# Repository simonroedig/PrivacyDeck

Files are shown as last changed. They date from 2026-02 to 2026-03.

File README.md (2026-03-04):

# PrivacyDeck

**Tangible Privacy Control. Zero Effort. Always Aware.**

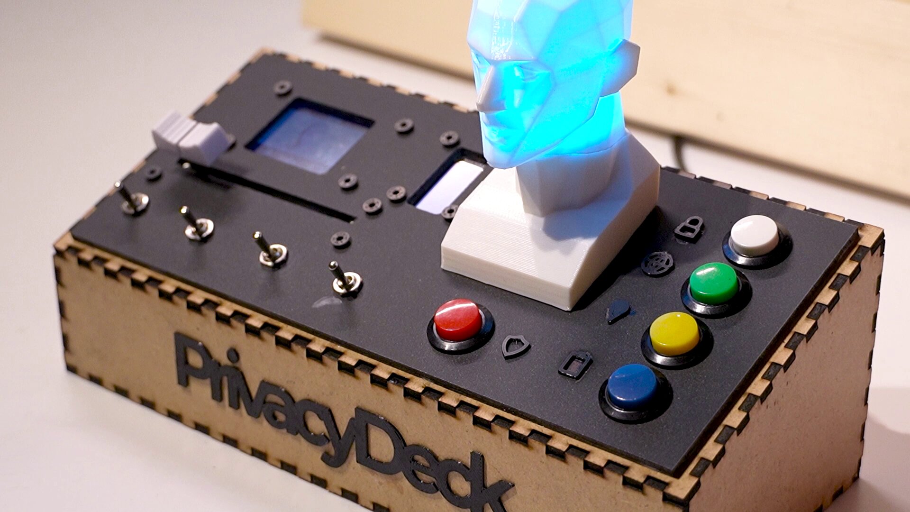
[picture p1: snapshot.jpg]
PrivacyDeck


*Built for the course **Practical Privacy and Security (PPS)** at LMU Munich*

---

## Video Demonstration:
<a href="https://www.youtube.com/watch?v=T16Eui8qbHk" target="_blank">
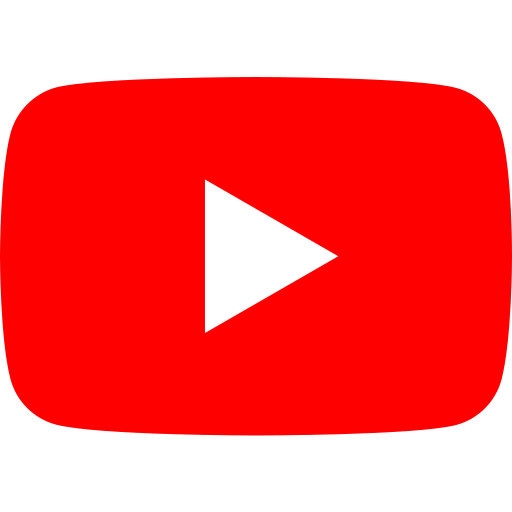
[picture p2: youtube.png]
Watch the video demonstration
    
</a>

## The Problem

Although privacy tools exist, they are buried deep inside complex, fragmented OS settings. There is **no unified control dashboard** and **no immediate feedback**.  
Most users therefore never enable protective features, preferring convenience over security — exposing themselves to risks such as unauthorized camera/microphone access, background data leaks, and embarrassing “always-on” moments.

## Our Vision

**PrivacyDeck envisions a world where privacy protection requires no effort.**  
Awareness alone is enough.  
No one ever has to worry about an embarrassing moment again.

---

## What is PrivacyDeck?

**PrivacyDeck** is a compact, USB-connected **physical control panel** that gives you **tangible, intuitive control** over all core privacy & security functions of your computer — at the press of a button or flip of a toggle.

- Personalized **avatar** on a small display that reflects your current privacy state via LEDs 
- Physical buttons, toggles & slider for instant action  
- Real-time visual & haptic feedback  
- Works with Linux (fully tested on Zorin OS), partially with Windows 11, and partially with macOS

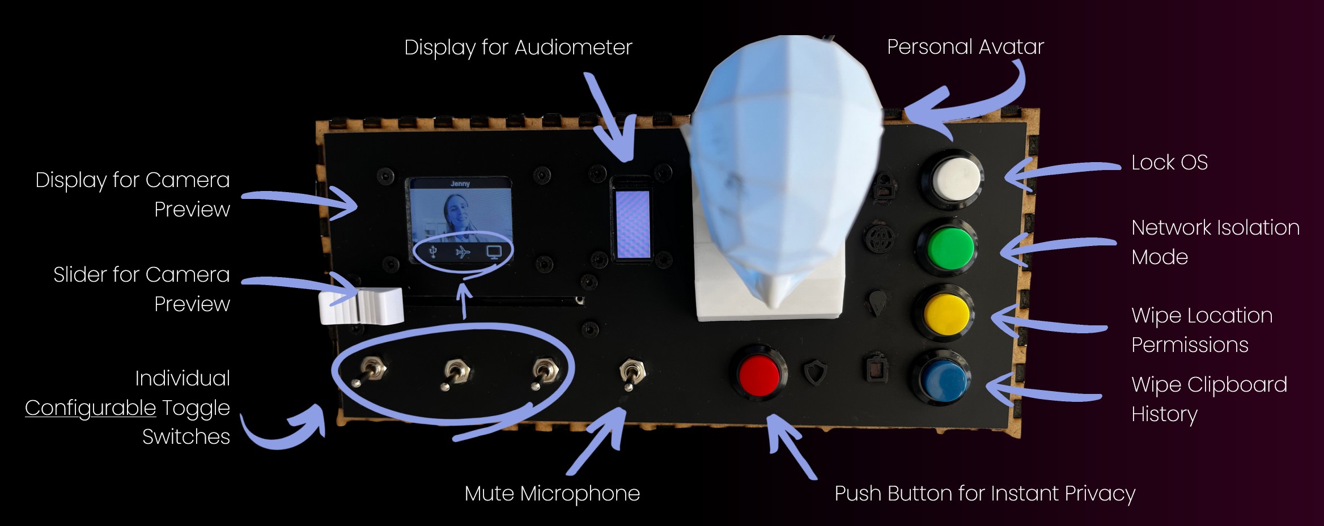
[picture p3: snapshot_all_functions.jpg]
All Functions Explained


---

## Repository Structure

```bash
PrivacyDeck/
├── verticalPrototype/                    # First working vertical prototype
├── 3d/                                   # All 3D-printable assets (avatar, etc.)
├── lasercut/                             # Laser-cut files for the case
│
├── privacyDeck/
│   ├── os/                               # Final OS-side daemon (Python)
│   │   └── final_main_os.py              # Main daemon – recommended on Linux
│   └── piPico/                           # Code for the Raspberry Pi Pico
│       └── final_main_pico.py            # Load as main.py on the Pico
│
└── guisoftware/                          # Graphical UI prototype (digital avatar + config)
```

---

## Hardware

- **Microcontroller**: Raspberry Pi Pico (RP2040)
- **Display**: Small TFT showing webcam and audio meter
- **Controls**: Buttons, toggles, slider, neopixel led
- **Connection**: Single USB cable (power + serial communication)

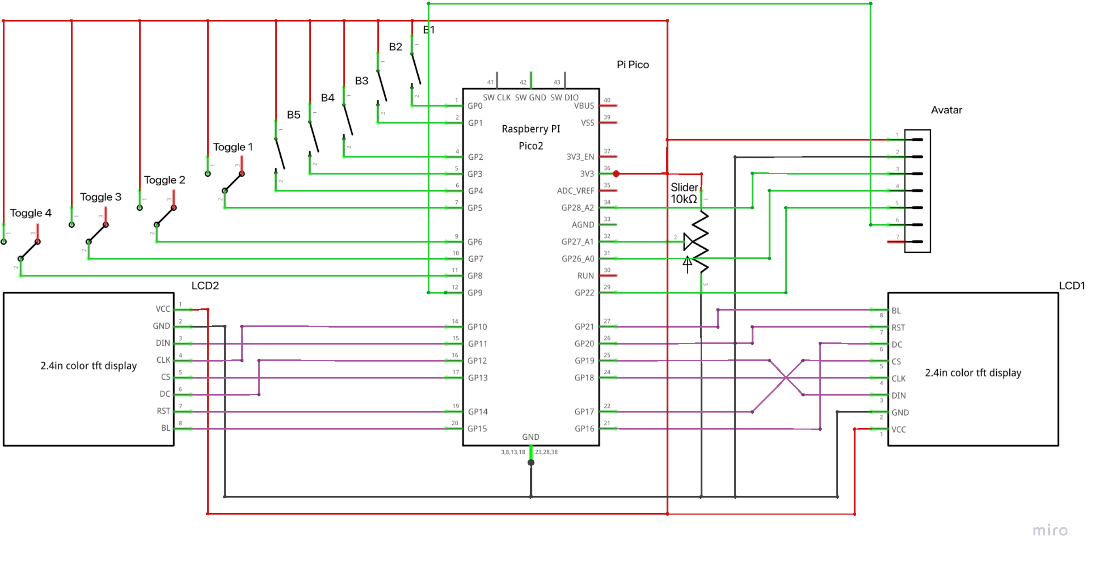
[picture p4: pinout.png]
Raspberry Pi Pico Pinout


**Early vertical prototype:**

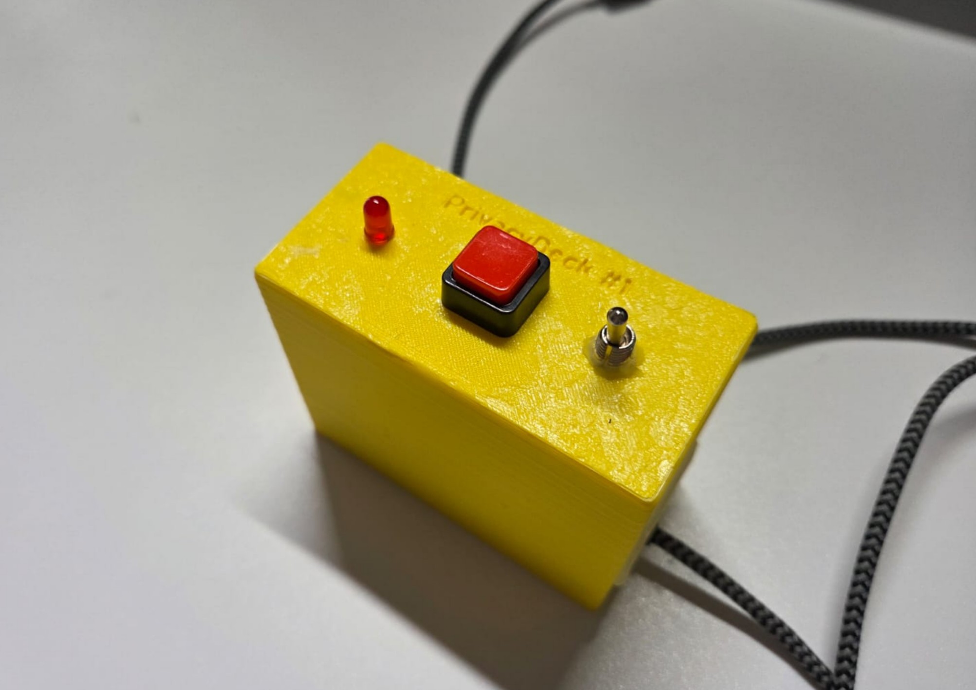
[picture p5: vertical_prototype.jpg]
Vertical Prototype


---

## Software

### 1. Raspberry Pi Pico (hardware side)
1. Copy `privacyDeck/piPico/final_main_pico.py` to the Pico as `main.py` and also include all other files
2. The Pico will automatically run and expose a serial port

### 2. Host OS Daemon (Linux / Windows)
1. `cd privacyDeck/os`
2. Make sure the serial port of the Pico is free
3. Run:
   ```bash
   python3 final_main_os.py
   ```
   (or `python final_main_os.py` on Windows)

**Tested & fully working on:**
- **Linux** – Zorin OS (primary development platform)
**Windows 11** – partially integrated (some triggers work with GUI solutions, full testing pending)
**macOS** – partially integrated (some triggers work, full testing pending)

### 3. GUI Software Prototype (optional but awesome)
Located in `guisoftware/`. Shows a beautiful digital avatar, live privacy status, and full configuration of every button/toggle.
Integration to the Python Daemon pending.

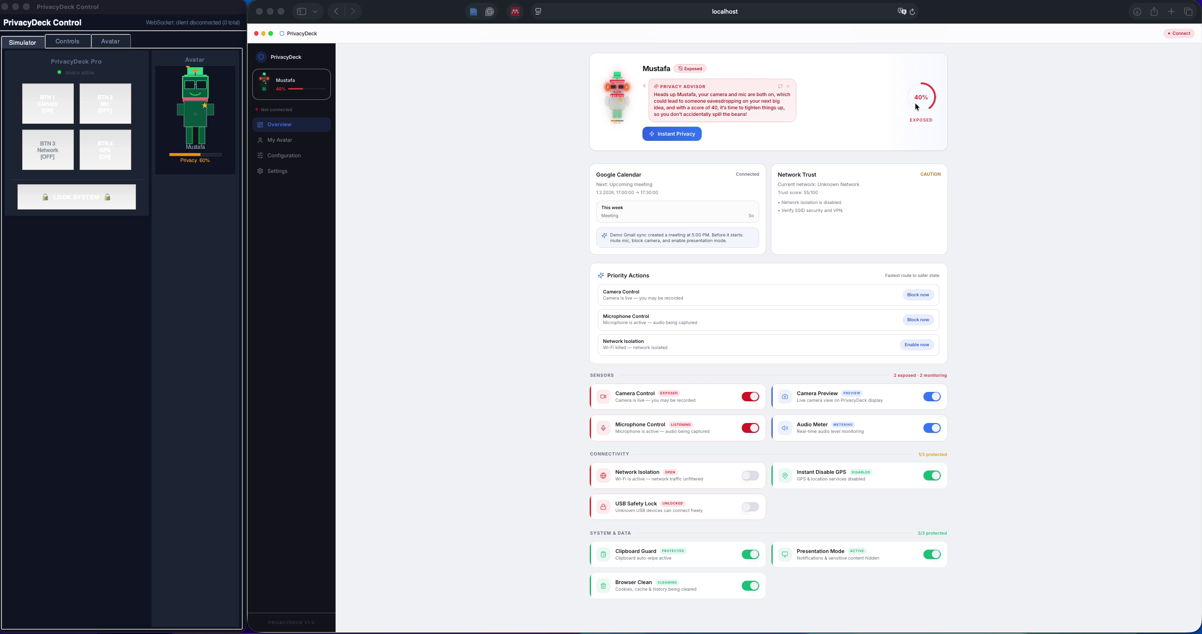
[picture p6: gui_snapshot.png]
GUI Prototype


---

## How to Get Started (Quick Guide)

1. Laser-cut the enclosure (`lasercut/`)
2. 3D-print the avatar holder and details (`3d/`)
3. Flash the Pico with `final_main_pico.py`
4. Connect everything via USB
5. Run `final_main_os.py` on your computer
6. Enjoy instant, physical privacy control!

---

## Team

- **Franziska Oberländer**
- **Mustafa Durani**
- **Tristan Häuser**
- **Simon Rödig** 

---

**Course**  
Practical Privacy and Security (PPS)  
Ludwig-Maximilians-Universität München (LMU)  
Winter Semester 2025/26

---

**Made with ❤️ for privacy that finally feels effortless.**

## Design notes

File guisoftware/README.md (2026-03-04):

# PrivacyDeck

A physical desktop privacy control panel — hardware-level privacy controls for macOS, paired with a companion dashboard app.

---

## What is PrivacyDeck?

PrivacyDeck is a two-part system:

1. **Physical device** — a microcontroller-based controller (current prototype appears to be ESP32-class hardware) that sits on your desk with buttons mapped to privacy features
2. **Companion dashboard** — a React/Vite app running locally on your Mac, showing real-time privacy status, a configurable avatar, and controls for all features

The two communicate via:
- **Wi-Fi TCP socket (port 50555)** — the hardware controller sends button events to the Python daemon
- **WebSocket (port 50556)** — the React dashboard connects to the daemon to read state, toggle features, and receive live updates

---

## Architecture

```
React Dashboard (Vite + TypeScript, port 8080)
  |  WebSocket ws://localhost:50556
Python Daemon (daemon/main.py)
  |  TCP :50555
Hardware Controller (buttons, LEDs)
```

---

## Current Hardware Status

- ✅ Physical button hardware has replaced the simulator.
- ℹ️ Based on the current prototype board shape/module, it appears to be an **ESP32 dev board** rather than a Raspberry Pi Pico; confirm by reading the silkscreen/chip label on the PCB (e.g. `ESP32`, `WROOM`, or RP2040-related marking).
- ⚠️ Main integration blockers encountered during bring-up:
  - Campus **eduroam restrictions** prevented reliable device-to-daemon networking.
  - **Python environment setup** issues delayed daemon-side testing and validation.

---

## Privacy Features

| Feature | Type | Active = |
|---|---|---|
| Camera Control | Exposure | Camera live (risk) |
| Microphone Control | Exposure | Mic active (risk) |
| Camera Preview | Monitor | Live preview on device display |
| Audio Meter | Monitor | Real-time level metering |
| Network Isolation | Protection | Wi-Fi killed (safe) |
| Instant Disable GPS | Protection | Location services off (safe) |
| USB Safety Lock | Protection | Unauthorised USB blocked (safe) |
| Clipboard Guard | Protection | Clipboard auto-wipe on (safe) |
| Presentation Mode | Protection | Notifications hidden (safe) |
| Browser Clean | Protection | Cache & cookie clearing active (safe) |

**Privacy Score (0–100%):**
- 40 pts — exposure safety (camera + mic both off = full 40)
- 60 pts — protection coverage (all guards enabled = full 60)

**Instant Privacy** — one button blocks all sensors and enables all protections simultaneously.

---

## Requirements

### Dashboard
- Node.js >= 18 or Bun

### Daemon
- Python 3.10+
- macOS (primary; Linux/Windows partial support)

---

## Getting Started

### 1. Start the Python daemon

```bash
cd daemon
python3 -m venv ../.venv
source ../.venv/bin/activate
pip install -r requirements.txt
python main.py
```

The daemon opens a Tkinter control window and starts the WebSocket server on `ws://localhost:50556`.

### 2. Start the React dashboard

```bash
npm install        # or: bun install
npm run dev        # http://localhost:8080
```

Open http://localhost:8080. The dashboard auto-connects to the daemon. Use the **Connect Device** button in the top bar if the connection indicator is red.

### 3. Configure and flash the hardware firmware

Edit `firmware/privacydeck_esp32/privacydeck_esp32.ino` before flashing:

- Set `WIFI_SSID` and `WIFI_PASSWORD` to a Wi-Fi network that your Mac and board can both access.
- Set `SERVER_HOST` to your Mac's LAN IP address (the machine running `python main.py`).
- Keep `SERVER_PORT` as `50555` unless you also change the daemon port.

Then flash the board from Arduino IDE / PlatformIO and open Serial Monitor at `115200` baud.

### 4. Verify button presses are registered in the dashboard

When connection is healthy, you should see this flow:

1. Hardware logs handshake success (`HELLO ...` / `HELLO_ACK ...`).
2. Daemon window logs `Pico TCP: connected ...` and then receives button events.
3. On press, firmware sends `EVENT BUTTON_1..4 pressed` (or `LOCK_BUTTON`).
4. Daemon responds `OK`, toggles the mapped feature, and broadcasts a WebSocket update.
5. Dashboard cards/status update immediately via `ack` / `feature_update` messages.

If presses do not appear in UI:

- Verify Mac firewall allows inbound TCP on `50555` and WS on `50556`.
- Ensure both devices are on a network that allows client-to-client traffic (many eduroam setups block this).
- Confirm button mappings in the dashboard Configuration page match expected features.
- Recheck firmware `SERVER_HOST` IP after reconnecting to a different network.

---

## Project Structure

```
privacy-dashboard-pro-main/
  daemon/
    main.py               Entry point, Tkinter GUI, server bootstrap
    ws_server.py          Async WebSocket server
    mic_control.py        Mute/unmute microphone
    webcam.py             Camera privacy level control
    audio_meter.py        Real-time audio level metering
    airplane.py           Wi-Fi kill switch (Network Isolation)
    location.py           GPS / Location Services toggle
    usb_alert_control.py  USB device alert/block
    clipboard_control.py  Clipboard wipe
    blackout.py           Screen blackout overlay
    lock_control.py       Trigger OS lock screen
    requirements.txt
  src/
    components/
      PrivacyAvatar.tsx   Robot SVG avatar with health bar and dead-eyes at 0%
      AppSidebar.tsx      Navigation sidebar with live privacy score bar
      MacOSChrome.tsx     Title bar with connection status indicator
    context/
      PrivacyContext.tsx  Feature state, WebSocket client, optimistic updates
      AvatarContext.tsx   Avatar customisation state
    pages/
      Overview.tsx        Main dashboard (feature cards + privacy score hero)
      Configuration.tsx   Physical button mapping
      AvatarPage.tsx      Full avatar customiser
      SettingsPage.tsx    App preferences
      AboutPage.tsx       About
    hooks/
      useWebSocket.ts     Reconnecting WebSocket with exponential backoff
```

---

## Avatar Health System

The robot avatar reflects your privacy score as a live health bar:

| Score | State | Visuals |
|---|---|---|
| 70–100% | Healthy | Green bar, full opacity body |
| 30–69% | At risk | Amber bar, reduced body opacity |
| 1–29% | Critical | Red bar, pulsing LOW HP badge |
| 0% | Dead | XX eyes, flat-line mouth, dizzy swirl, faded body |

---

## WebSocket Protocol

All messages are JSON over `ws://localhost:50556`.

**Daemon → Dashboard:**

| Type | Payload | When |
|---|---|---|
| `state` | `{ features, buttonMapping }` | On connect |
| `ack` | `{ featureId, active, success }` | After toggle |
| `feature_update` | `{ featureId, active }` | Push update |
| `error` | `{ message, featureId? }` | On failure |

**Dashboard → Daemon:**

| Type | Payload | Action |
|---|---|---|
| `toggle` | `{ featureId }` | Toggle a feature |
| `get_state` | — | Request full state snapshot |
| `set_button_mapping` | `{ mapping: string[] }` | Update button assignments |

---

## Running Tests

```bash
npm test            # single run
npm run test:watch  # watch mode
```

---

## License

MIT

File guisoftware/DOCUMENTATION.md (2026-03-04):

# PrivacyDeck — Technical Documentation

## Overview

PrivacyDeck is a hardware-software privacy control system. A physical ESP32 device sits on the desk with buttons mapped to privacy features. A Python daemon runs in the background executing OS-level privacy controls. A React dashboard provides real-time visual feedback and configuration.

---

## System Architecture

```
┌─────────────────────┐        TCP :50555         ┌──────────────────────┐
│  ESP32 Firmware     │ ────────────────────────▶ │  Python Daemon       │
│  (C++ / Arduino)    │   button events / ping     │  daemon/main.py      │
└─────────────────────┘                            └──────────┬───────────┘
                                                              │ WebSocket :50556
                                                              ▼
                                                   ┌──────────────────────┐
                                                   │  React Dashboard     │
                                                   │  (TypeScript / Vite) │
                                                   └──────────────────────┘
```

Three communication channels:
- **TCP (port 50555)** — Hardware → Daemon. Custom text protocol for button events and keepalive.
- **WebSocket (port 50556)** — Daemon ↔ Dashboard. JSON messages for state sync, toggles, and acks.
- **HTTPS / OAuth2** — Dashboard + Daemon → Google Calendar API. Token exchange handled by daemon.

---

## Languages and Stack

### Hardware Layer — `firmware/`
| | |
|---|---|
| Language | C++ (Arduino framework) |
| Platform | ESP32 (Espressif) |
| IDE | Arduino IDE / PlatformIO |
| Protocol | Custom TCP text protocol over Wi-Fi |

### Daemon Layer — `daemon/`
| | |
|---|---|
| Language | Python 3.10+ |
| Key libraries | `websockets` (async WS server), `tkinter` (GUI control window), `python-dotenv` (env vars), `subprocess` (OS commands) |
| Primary OS | macOS (partial Linux/Windows support) |
| Entry point | `daemon/main.py` (1672 lines) |

### Dashboard Layer — `src/`
| | |
|---|---|
| Language | TypeScript 5.8 |
| Framework | React 18.3 |
| Build tool | Vite 5.4 (dev server on port 8080) |
| Styling | Tailwind CSS 3.4 |
| Component library | Radix UI + shadcn/ui patterns |
| Animations | Framer Motion |
| Icons | Lucide React |
| State | React Context API |
| Forms | React Hook Form + Zod |
| Routing | React Router v6 |
| Testing | Vitest + Testing Library |
| Package manager | npm or Bun |

---

## How It Works

### 1. Startup sequence
1. Run `python daemon/main.py` — opens Tkinter control window, starts TCP server on `:50555`, starts WebSocket server on `:50556`.
2. Run `npm run dev` — dashboard serves on `http://localhost:8080`, auto-connects to `ws://localhost:50556`.
3. Power the ESP32 — it connects to Wi-Fi, opens a TCP connection to the daemon, and sends a handshake: `HELLO PRIVACYDECK_PICO 1`.

### 2. Button press flow
```
User presses physical button
  → ESP32 sends: EVENT BUTTON_1 pressed
  → Daemon receives, maps button to feature (e.g. mic-control)
  → Daemon executes OS control (e.g. mic_control.py mutes mic)
  → Daemon broadcasts: { type: "feature_update", featureId: "mic-control", active: true }
  → Dashboard receives update, re-renders feature card and avatar
```

### 3. Dashboard toggle flow
```
User clicks toggle in dashboard
  → Optimistic UI update (instant, no wait)
  → Sends: { type: "toggle", featureId: "network" } over WebSocket
  → Daemon executes OS control (e.g. airplane.py kills Wi-Fi)
  → Daemon sends: { type: "ack", featureId: "network", active: true, success: true }
  → Dashboard confirms state, clears pending lock (2-second race-condition window)
```

### 4. Privacy score
Computed in `PrivacyContext.tsx` on every state change:

```
score = exposureScore + protectionScore

exposureScore  = ((2 - exposuresActive) / 2) × 40    // camera, mic
protectionScore = (protectionsActive / 6) × 60         // network, gps, usb, clipboard, presentation, browser-clean
```

Range: 0–100. Drives avatar health state and sidebar bar colour.

---

## Privacy Features (10 total)

| ID | Name | Type | OS action |
|---|---|---|---|
| `camera-control` | Camera Control | Exposure | Blocks camera hardware access |
| `mic-control` | Microphone Control | Exposure | Mutes system microphone |
| `camera-preview` | Camera Preview | Monitor | Live camera feed on device display |
| `audio-meter` | Audio Meter | Monitor | Real-time audio level widget |
| `network` | Network Isolation | Protection | Wi-Fi kill switch (airplane mode) |
| `gps` | Instant Disable GPS | Protection | Disables location services |
| `usb-lock` | USB Safety Lock | Protection | Blocks unauthorised USB connections |
| `clipboard` | Clipboard Guard | Protection | Auto-wipes clipboard |
| `presentation` | Presentation Mode | Protection | Hides notifications |
| `browser-clean` | Browser Clean | Protection | Clears cookies, cache, history |

**Instant Privacy**: one action toggles all 10 features to maximum privacy.

---

## Daemon Modules

| File | Responsibility |
|---|---|
| `main.py` | Core server, Tkinter GUI, feature state, button mapping, calendar recommendations |
| `ws_server.py` | Async WebSocket server (bridges dashboard ↔ daemon) |
| `mic_control.py` | Cross-platform microphone mute/unmute |
| `webcam.py` | Camera access control |
| `audio_meter.py` | Real-time audio metering widget |
| `airplane.py` | Wi-Fi kill switch |
| `location.py` | GPS / location services toggle |
| `usb_alert_control.py` | USB device alert and block |
| `clipboard_control.py` | Cross-platform clipboard wipe |
| `blackout.py` | Screen blackout overlay |
| `lock_control.py` | Triggers OS lock screen |

---

## Dashboard Components

| File | Responsibility |
|---|---|
| `context/PrivacyContext.tsx` | Feature state, WebSocket client, optimistic updates, study logging, calendar state |
| `context/AvatarContext.tsx` | Avatar customisation state (persisted to localStorage) |
| `components/PrivacyAvatar.tsx` | SVG robot avatar; body parts mapped to features with glow indicators |
| `components/AppSidebar.tsx` | Navigation with live privacy score bar |
| `components/MacOSChrome.tsx` | Title bar with connection status |
| `pages/Overview.tsx` | Main dashboard — feature cards, score hero, avatar |
| `pages/Configuration.tsx` | Physical button mapping UI |
| `pages/AvatarPage.tsx` | Avatar appearance customiser |
| `pages/SettingsPage.tsx` | App preferences, study mode, calendar settings |
| `hooks/useWebSocket.ts` | Reconnecting WebSocket with exponential backoff |

---

## Avatar Health System

The robot avatar (`PrivacyAvatar.tsx`) maps each feature to a body part:

| Body part | Feature |
|---|---|
| Eyes | Camera control / Camera preview |
| Mouth | Microphone control |
| Ears | Audio meter |
| Head | Presentation mode |
| Torso | Network isolation |
| Arms | USB safety lock |
| Hands | Clipboard guard |
| Feet | GPS |
| Antenna | Browser clean |

Health states driven by privacy score:

| Score | State | Visual |
|---|---|---|
| 70–100 | Healthy | Green bar, full opacity |
| 30–69 | At risk | Amber bar, reduced opacity |
| 1–29 | Critical | Red bar, pulsing LOW HP badge |
| 0 | Dead | XX eyes, flat-line mouth, dizzy swirl |

Active exposure features glow **red**; active protection features glow **green**.

---

## WebSocket Protocol

All messages are JSON over `ws://localhost:50556`.

**Daemon → Dashboard**

| `type` | Key fields | Sent when |
|---|---|---|
| `state` | `features`, `buttonMapping` | On dashboard connect |
| `ack` | `featureId`, `active`, `success` | After toggle executed |
| `feature_update` | `featureId`, `active` | External state change (hardware button) |
| `error` | `message`, `featureId?` | Execution failure |
| `google_token` | `accessToken`, `expiresAt` | OAuth2 code exchange complete |

**Dashboard → Daemon**

| `type` | Key fields | Action |
|---|---|---|
| `toggle` | `featureId` | Execute feature toggle |
| `get_state` | — | Request full state snapshot |
| `set_button_mapping` | `mapping: string[]` | Update button assignments |
| `google_oauth_exchange_code` | `code`, `state` | Exchange OAuth2 authorization code |

---

## Hardware Protocol (TCP)

Custom text-based protocol on port 50555.

```
ESP32  →  Daemon:   HELLO PRIVACYDECK_PICO 1
Daemon →  ESP32:    HELLO_ACK 1

ESP32  →  Daemon:   EVENT BUTTON_1 pressed
Daemon →  ESP32:    OK

ESP32  →  Daemon:   PING
Daemon →  ESP32:    PONG
```

Button pin mapping (default firmware):

| GPIO | Button | Default feature |
|---|---|---|
| 12 | Button 1 | camera-control |
| 13 | Button 2 | mic-control |
| 14 | Button 3 | network |
| 15 | Button 4 | gps |
| 16 | Lock button | OS lock screen |
| 2 | — | Status LED |

Debounce: 50 ms. Reconnection: exponential backoff (2 s → 30 s max).

---

## Google Calendar Integration

The daemon acts as a secure proxy for OAuth2 token exchange:

1. Dashboard constructs Google OAuth2 authorization URL and redirects user.
2. After consent, Google redirects back with an authorization code.
3. Dashboard sends `google_oauth_exchange_code` over WebSocket to daemon.
4. Daemon POSTs to `https://oauth2.googleapis.com/token` using credentials from `.env`.
5. Daemon returns `accessToken` and `expiresAt` to dashboard.
6. Dashboard calls Google Calendar API directly using the token.

The daemon also generates calendar-aware privacy recommendations by combining:
- Meeting timing and density (meetings within 20 min or 3+ meetings today)
- Network trust heuristic (derived from network isolation toggle state)
- Current protection feature states

---

## Study Data Logging

When enabled in settings, `PrivacyContext.tsx` logs every feature transition to `localStorage`:

```typescript
{
  timestamp: string,       // ISO 8601
  featureId: string,
  featureName: string,
  before: boolean,
  after: boolean,
  source: "dashboard" | "daemon",
  scoreBefore: number,
  scoreAfter: number
}
```

Max 2000 entries retained. Exportable as JSON from Settings. Never transmitted — local only.

---

## Running the Project

```bash
# Daemon
cd daemon
python3 -m venv ../.venv && source ../.venv/bin/activate
pip install -r requirements.txt
python main.py

# Dashboard
npm install
npm run dev        # http://localhost:8080

# Tests
npm test
```

---

## License

MIT

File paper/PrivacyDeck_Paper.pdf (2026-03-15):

# PrivacyDeck: A Tangible Interface for Low-Friction Desktop Privacy Management

## Mustafa Durani

Ludwig Maximilian University of Munich

Management and Digital Technologies

Munich, Germany

m.durani@campus.lmu.de

## Tristan Häuser

Ludwig Maximilian University of Munich

Media Informatics

Munich, Germany

tristan.haeuser@campus.lmu.de

## Franziska Oberländer

Ludwig Maximilian University of Munich

Management and Digital Technologies

Munich, Germany

f.oberlaender@campus.lmu.de

# Simon Rödig

Ludwig Maximilian University of Munich

Human-Computer Interaction

Munich, Germany

simon.roedig@campus.lmu.de

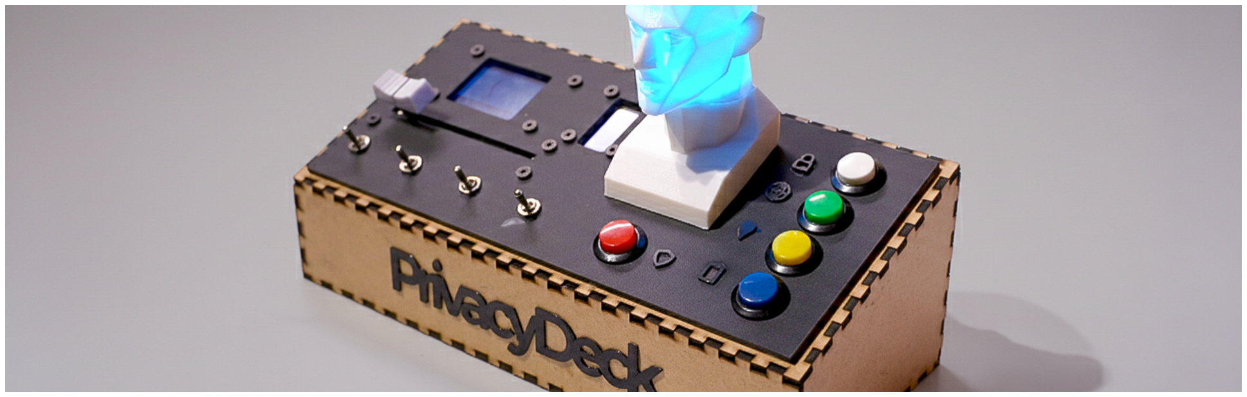
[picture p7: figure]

Figure 1: The PrivacyDeck tangible control panel placed on a desktop workspace, providing direct physical control over privacy

and security functions. Video demonstration: https://www.youtube.com/watch?v=T16Eui8qbHk

### Abstract

Protecting personal privacy on desktop computers remains cum-

bersome despite available system controls. Critical privacy features

are often buried within complex menus, fragmented across applica-

tions, and lack immediate, interpretable feedback, leading users to

neglect protective actions in favour of convenience.

We present PrivacyDeck, a tangible, USB-connected control

panel that externalises high-frequency privacy actions into per-

sistent physical controls. Users can lock the operating system, mute

the microphone, and manage camera and connectivity settings with

single gestures, while a modular personalised avatar provides real-

time visual feedback on system exposure. The hardware integrates

buttons, toggles, SPI screens, a slider, and an avatar with LEDs,

communicating with an OS-level Python daemon and a graphical

dashboard.

Initial deployment illustrates reliable operation on Linux with

low-latency feedback, while exposing platform-specific limitations

This work is licensed under a Creative Commons Attribution-ShareAlike 4.0 Interna-

tional License. (https://creativecommons.org/licenses/by-sa/4.0)

on Windows and macOS that underscore the need for a unified,

open framework for cross-platform privacy and security functions.

PrivacyDeck suggests that tangible interfaces can meaningfully

reduce interaction friction in everyday privacy management, and

that future devices would benefit from standardised system-level

privacy APIs supporting proactive, situation-aware user behaviour.

# CCS Concepts

- Human-centered computing → Human computer interac-

# tion (HCI); Interaction design; • Security and privacy → Usability in security and privacy; Human and societal aspects of security

and privacy.

### Keywords

privacy management, tangible user interfaces, usable security, desk-

top privacy, physical computing, privacy awareness, situation aware-

ness, ambient displays, mixed-initiative interfaces, explainable feed-

back, privacy fatigue, hardware privacy controls, avatar-based feed-

## back

## Mustafa Durani, Tristan Häuser, Franziska Oberländer, and Simon Rödig

### 1 Introduction & Motivation

Protecting personal privacy on everyday computing devices re-

mains unnecessarily difficult. Privacy failure is not primarily a

knowledge problem, but a friction problem: although protective

tools and settings are technically available, they are often buried

within complex, nested operating system menus and fragmented

across multiple applications. Users must navigate unintuitive inter-

faces, remember hidden shortcuts, and manage app-specific controls

without a unified dashboard.

This complexity leads to the underutilisation of critical privacy

features and the neglect of basic protective behaviours in favour of

convenience, reducing users’ sense of control [3]. The absence of

centralised management and the lack of immediate, tangible feed-

back about privacy states, such as whether a camera or microphone

is active, further amplify uncertainty and discomfort, especially

when control appears to be taken away [2, 12].

As a result, current privacy management systems fail not because

users are unaware of risks, but because interaction barriers, frag-

mented controls, and unclear feedback prevent timely, confident,

and effective privacy action.

To address these challenges, the PrivacyDeck was developed: a

compact, USB-connected physical control panel that moves high-

frequency privacy actions out of fragmented software menus and

into dedicated, always-accessible physical controls. By moving pri-

vacy management into a persistent tangible form, the device reduces

the interaction overhead that prior work identifies as the primary

barrier to consistent privacy behaviour [3, 12].

By placing controls directly on the desk within constant reach,

the PrivacyDeck transforms passive security awareness into proac-

tive behaviour. Instead of requiring users to navigate software

menus under cognitive load, each protective action is reduced to a

single physical gesture, building the kind of muscle memory that

makes privacy protection sustainable across shared office environ-

ments, remote work settings, and public spaces.

### 2 Related Work

Researchers have pursued several approaches to closing the gap be-

tween privacy awareness and protective action, spanning software

dashboards, tangible interaction frameworks, physical device proto-

types, and icon design studies. Each addresses part of the problem;

none fully resolves the combination of fragmented controls, absent

feedback, and high interaction cost that defines everyday privacy

management.

### 2.1 Software Dashboards

The most established approach is the software dashboard. Farke

et al. [7] evaluated Google’s My Activity, a transparency tool that

lets users review and delete activity data collected across Google

services. They found that while the tool surprised users with the

volume of data collected, participants largely neither engaged with

its control features nor changed their behaviour afterward. Thus,

, transparency alone is insufficient to motivate protective action.

Alashwali et al. [3] documented a parallel pattern in remote work:

workers commonly experience privacy invasions during video calls,

such as accidental camera or microphone exposure, yet only a mi-

nority take active countermeasures despite being aware of the risk.

Shao et al. [16] formalised this disengagement as privacy fatigue,

showing that repeated exposure to complex privacy decisions leads

users to abandon protective behaviour entirely. Together, these

findings establish that software based transparency and control

tools tend to fall short when they demand sustained effort across

fragmented interfaces. The PrivacyDeck responds to this by mov-

ing core privacy controls out of software menus and onto a single

physical surface where each action requires one gesture.

### 2.2 Shared and Cognitively Demanding

### Environments

A second line of research examines why privacy breaks down in

shared and cognitively demanding environments. Song et al. [18]

studied account sharing in the workplace and found it to be wide-

spread, with collaboration across shared accounts serving as a norm

rather than an exception. While their work surfaces important chal-

lenges around access control and activity accountability, it does not

address the resulting problem of ambiguous privacy state across

sessions and users: when multiple people move through the same

device or account, it becomes unclear what sensors are active, what

data has been left behind, and what the current exposure level actu-

ally is. Endsley [6] provides a theoretical explanation for why this

ambiguity is so consequential: under multitasking or cognitive load,

situation awareness degrades in predictable and systematic ways,

causing users to lose track of environmental states that require

ongoing monitoring. Applied to shared workspaces, this means

that even users who intend to manage their privacy actively are

likely to miss critical state changes when attention is divided. The

PrivacyDeck addresses this by externalising privacy state through

persistent hardware indicators and an avatar that communicates

risk at a glance, without requiring active monitoring or memory.

### 2.3 Tangible and Physical Interfaces

A third strand of work has proposed tangible and physical inter-

faces as alternatives to software controls. Ahmad et al. [2] studied

how bystanders perceive IoT devices such as cameras and voice

assistants and found that ambiguous device states, where “off” does

not necessarily mean fully deactivated, create persistent uncer-

tainty about whether recording is occurring. They introduced the

concept of tangible privacy, recommending that devices convey

sensor states through unambiguous physical indicators, hardware

switches, and camera shutters, though their contribution remained

at the level of design principles rather than a deployable system.

The practical consequences of this ambiguity are measurable even

outside IoT contexts. Portnoff et al. [15] found that only 45% of par-

ticipants noticed an active webcam LED during ordinary computing

tasks, a figure that fell to just 5% when attention was directed else-

where. Even when physical feedback mechanisms exist, they can

routinely fail under the realistic conditions of divided attention that

characterise everyday desk work. Mehta et al. [12] operationalised

these principles further by developing Privacy Care, an interaction

framework for tangible privacy management in ubiquitous com-

puting. The framework establishes Awareness and Control as core

design goals and defines three interaction tenets, namely Direct,

Ready to Hand, and Contextual, to guide the design of physical

privacy tools. However, Privacy Care was validated through focus

## PrivacyDeck: A Tangible Interface for Low-Friction Desktop Privacy Management

groups with older adults rather than as an implemented device for

everyday desktop use, which limits its direct applicability to the

present context. Al Muhander et al. [13] came closest to implemen-

tation with PriviFy, a tangible interface for configuring IoT privacy

preferences using knobs, buttons, lights, and notifications. Across

iterative design sessions and a subsequent high-fidelity evaluation

totalling forty participants, PriviFy achieved higher usability scores

and lower perceived effort than conventional software controls,

confirming that consistent, physically uniform controls support

ease of use. However, as an arXiv preprint, these findings await for-

mal peer review. PriviFy is also scoped to IoT device configuration

and does not address desktop privacy functions such as camera

and microphone control, clipboard management, or system locking.

The PrivacyDeck extends this by implementing a fully functional

physical panel for core desktop privacy actions, combining dedi-

cated hardware switches with real-time visual feedback through

LEDs, a live camera preview, and an audiometer for microphone

input.

### 2.4 Visual Communication and Icon Design

Finally, researchers have investigated how visual communication

affects the usability of privacy interfaces. Delgado Rodriguez et

al. [5] elicited and clustered symbols and metaphors associated with

privacy and security through brainstorming sessions and expert

evaluation, finding that camera and microphone symbols were

consistently grouped under privacy-related themes. While their

sample was small and the study exploratory, the findings identify

recognisable visual anchors for privacy interface design. Habib et

al. [9] tested how effectively icons and link texts convey privacy

choices and found that unfamiliar or ambiguous symbols without

accompanying text frequently cause misinterpretation, establishing

that icons alone are insufficient to communicate intent reliably.

The PrivacyDeck incorporates both insights: each physical control

is paired with a widely recognised icon and a printed text label,

ensuring interpretability without prior familiarity with the device.

### 2.5 Summary

Across these four areas, a consistent gap emerges. Software dash-

boards provide transparency but not low effort action. Tangible pri-

vacy frameworks offer strong design principles but lack implemen-

tation for desktop environments. Physical prototypes demonstrate

feasibility but remain scoped to IoT contexts. Icon research identi-

fies effective symbols but cautions against deploying them without

accompanying text. The PrivacyDeck integrates these contributions

into a single device that consolidates fragmented controls, makes

system state continuously visible through hardware feedback, and

reduces each protective action to a physical gesture requiring no

software navigation.

### 3 PrivacyDeck: Concept

PrivacyDeck is built around the core idea of tangible, low-friction

privacy management through persistent physical controls and un-

ambiguous ambient feedback. High-frequency privacy actions, such

as locking the operating system, muting the microphone, blocking

the camera, isolating the network, or clearing sensitive data, are

mapped to dedicated physical buttons and toggles on the control panel. This externalisation eliminates the need to navigate soft-

ware menus, enabling single-gesture activation that builds muscle

memory for consistent use in any desktop context.

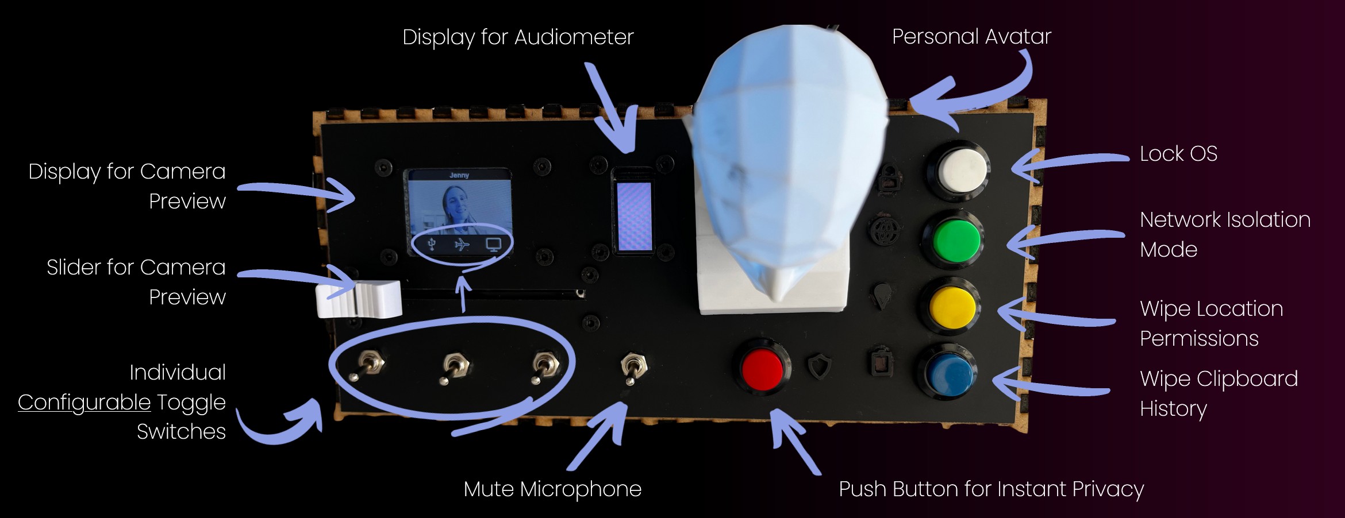
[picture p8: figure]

Figure 2: All components of PrivacyDeck and their respective

functions.

The feedback mechanism is designed to be glanceable and non-

intrusive, following calm technology principles [21]. The center-

piece is the modular, customisable avatar, which serves as both a

personal companion and an ambient display using a NeoPixel LED

ring and optical fibers. Key features include:

- Camera status: The avatar’s eyes light up in red when the

webcam is active.

- Microphone status: The mouth illuminates in red when

the microphone is recording.

- Contextual LED cues: Remaining LEDs illuminate in

context-specific colours synchronised with the correspond-

ing privacy buttons to signal pending actions and prompt

the user. For example:

– Blue when clipboard history exceeds 5 entries (prompt-

ing clear)

– Green when browser tracking or cookies surpass a

threshold (prompting protection)

- Optimal privacy state: When all critical sensors are de-

activated, protections are enabled, and data is cleared, the

avatar and button LEDs remain unlit, providing a distraction-

free confirmation of full protection.

- Instant privacy button: Pressing this triggers all neces-

sary actions in sequence, with the avatar briefly flashing all

LEDs red as visual confirmation before all lights extinguish

upon completion.

This hardware-centric feedback is complemented by the software

dashboard, which provides:

- A composite privacy score
- Real-time monitoring (camera preview, audio meter)
- Customisation options for the avatar’s appearance
- An explainable Privacy Advisor offering contextual recom-

mendations without interrupting workflow

By combining direct physical control with peripheral LED-based

awareness, PrivacyDeck addresses privacy fatigue by making pro-

tective actions effortless and the system state intuitively perceptible

at all times.

### 4 Implementation

As a foundation for the implementation, a true-to-scale Figma pro-

totype enabled iterative testing of element sizes and positions as shown in Figure 3. To evaluate ergonomics, proportions, and com-

ponent placement, 3D paper prototypes were developed. In general,

controls are organised across the deck into coherent spatial zones

with consistent component types such as push buttons, toggles,

and displays to support usability, findability, and reduced cognitive

load in line with Muhander et al. [13].

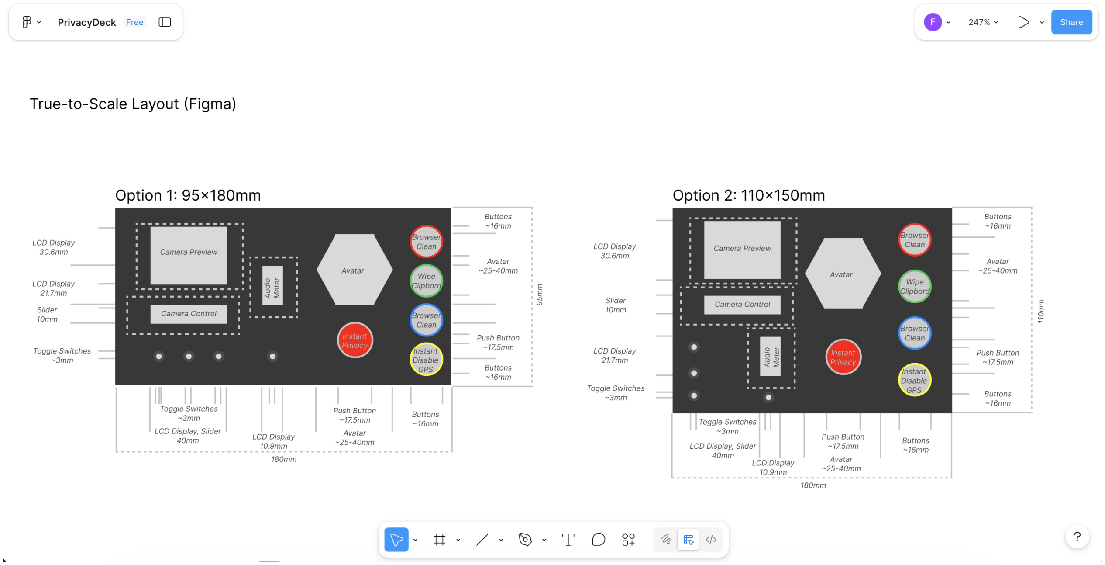
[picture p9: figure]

Figure 3: True-to-scale Figma screens for two potential lay-

outs.

### 4.1 First Vertical Prototype

Before implementing the full system architecture, we developed

an early vertical prototype to validate core end-to-end functional-

ity. This prototype supported only two essential actions: locking

the operating system and muting the microphone. The goal was

not feature completeness, but architectural validation—testing the

complete signal chain from physical input on the microcontroller,

through serial communication, to OS-level execution and state

feedback. By confirming reliable, low-latency system-level triggers

early, we reduced integration risks before expanding the hardware

and software stack.

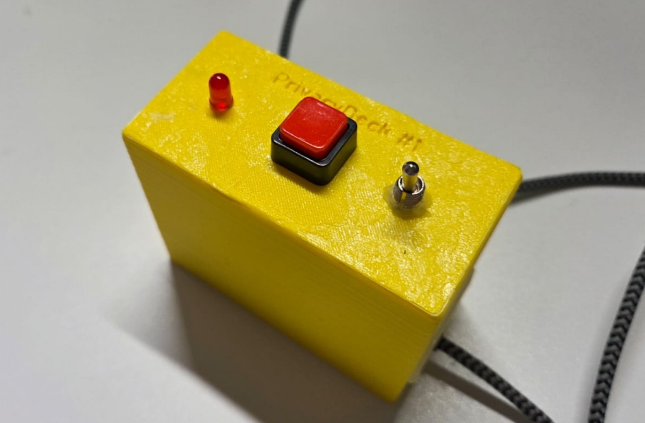
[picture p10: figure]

Figure 4: Early vertical prototype supporting OS lock and

microphone mute functionality.

### 4.2 Hardware

# 4.2.1 Hardware Implementation. The hardware development pro-

cess followed an iterative prototyping approach, beginning with

the systematic testing of each individual component using dedi-

cated test scripts. All electronic parts—including buttons, switches,

LEDs, the microcontroller, and the NeoPixel elements were vali-

dated independently to ensure stable operation before integration.

In parallel, all physical components were precisely measured to

enable an accurate enclosure design.

The housing (Figure 5) was laser-cut from a parametric box

template adapted from https://boxes.hackerspace-bamberg.de and

refined over two iterations to match the PrivacyDeck dimensions.

The top deck plate (Figure 6) was designed from scratch in Shapr3D

(https://www.shapr3d.com/) and iteratively adjusted to ensure sta-

ble, ergonomic placement of all controls.

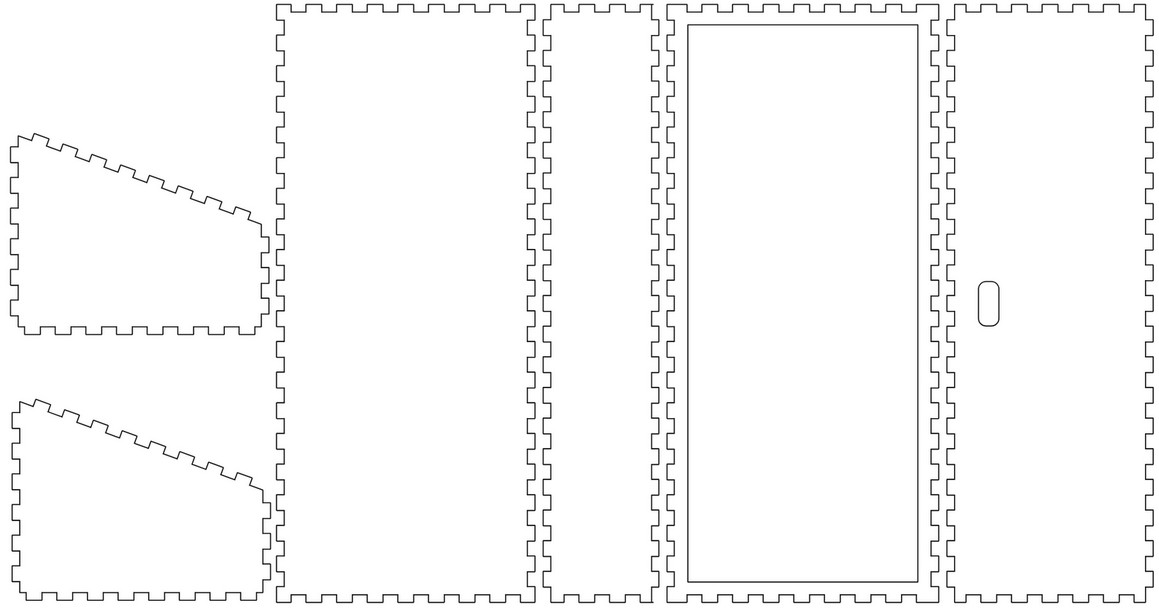
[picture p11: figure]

Figure 5: Laser-cut enclosure based on an adapted parametric

box template.

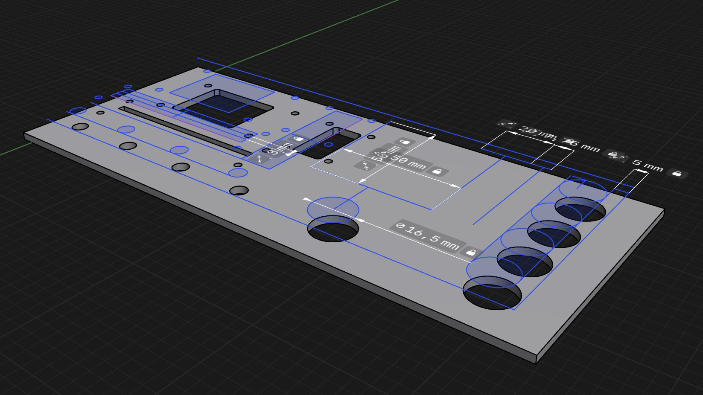
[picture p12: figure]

Figure 6: Custom-designed deck plate holding the individual

hardware components.

After finalising the enclosure geometry, all components were

installed and soldered, resulting in a compact and mechanically

stable assembly.

# 4.2.2 Avatar Design and Fabrication. The avatar component rep-

resented the most technically demanding aspect of the hardware

implementation. Rather than relying on an existing model, we de-

signed a custom 3D model from scratch to meet both aesthetic and

functional requirements. To enable internal hardware integration,

the model was deliberately divided into three separate 3D-printable

subcomponents: a base structure, a mid-section housing the elec-

tronics, and a detachable head element. This modular design al-

lowed wiring and component placement prior to final assembly.

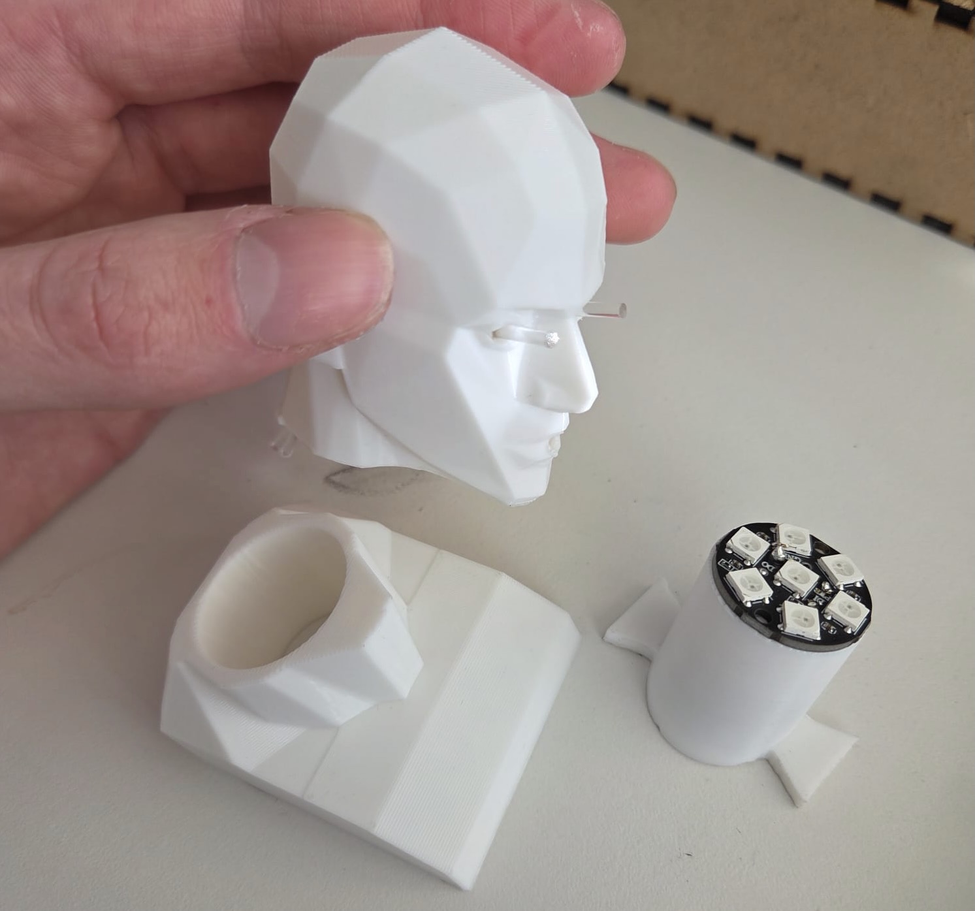
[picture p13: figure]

(a) The avatar divided into three 3D-printable components for modu-

lar assembly.

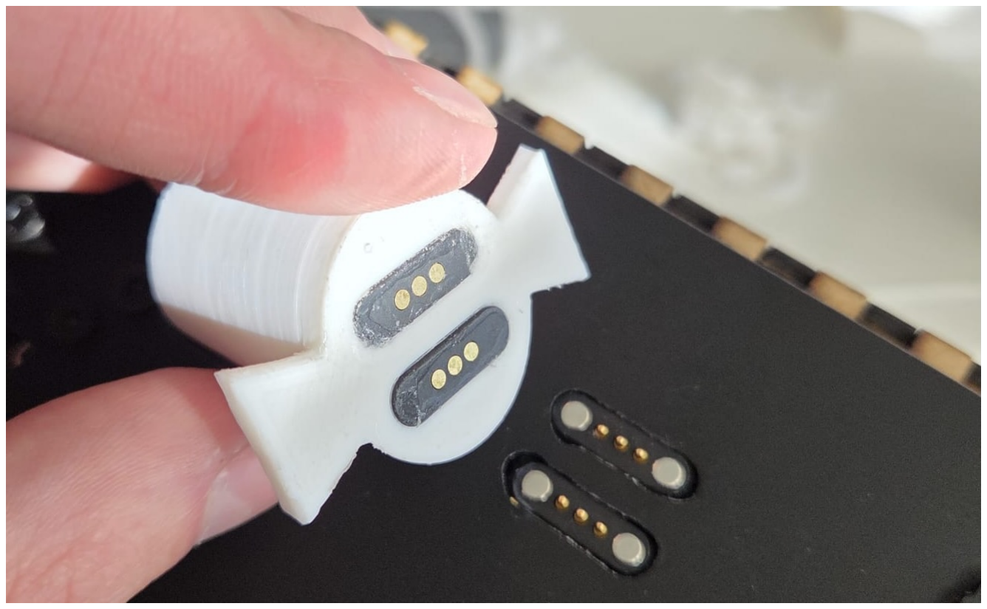
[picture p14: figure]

(b) Magnetic pogo-pin interface enabling snap-on avatar attachment.

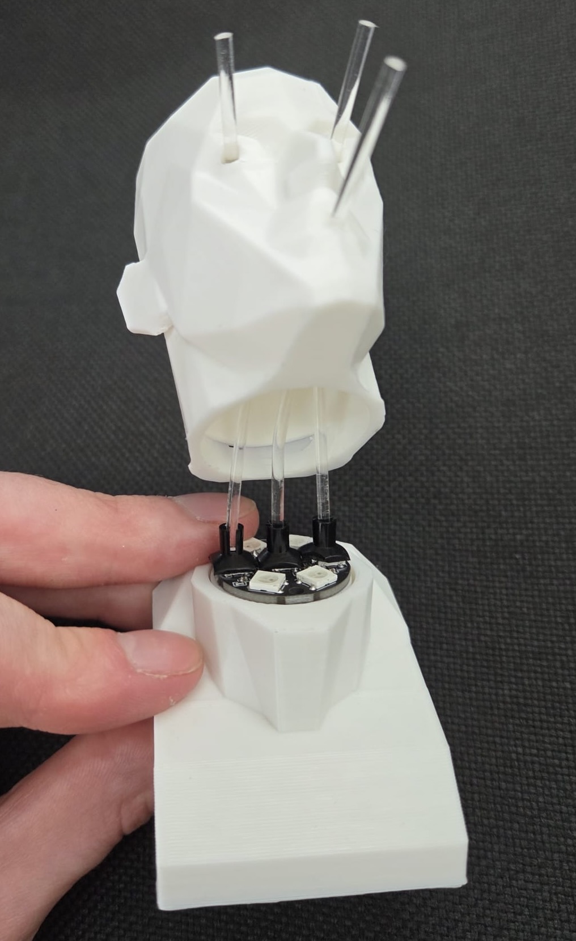
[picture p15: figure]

(c) NeoPixel ring and optical fibre routing to the avatar’s eyes and

mouth.

Figure 7: Hardware construction and integration of the modular avatar component.

The avatar underwent three print iterations to optimise struc-

tural stability, internal spacing, and surface finish. Each avatar

contains a NeoPixel ring with seven RGB LEDs. Three of these

LEDs are optically routed to the avatar’s eyes and mouth using

optical fibres. The fibres channel light precisely from the LEDs to

the eyes and mouth, in order to convey when the webcam is on

(eyes) or the microphone is recording audio (mouth).

Integrating the optical fibres required substantial manual refine-

ment. The fibres were fixed directly above selected LEDs and shaped

using controlled heat application to achieve precise alignment with

the eye and mouth openings. Covering each fibre with opaque tape

would have reduced light scatter to other parts of the avatar.

# 4.2.3 Avatar Mounting and Electrical Connection. To allow mod-

ular attachment, the avatar connects to the PrivacyDeck using a magnetic pogo-pin interface. Two 3-pin pogo connectors were in-

tegrated: one part embedded in the deck and the corresponding

counterpart installed inside the avatar base. Magnets integrated

into the pogo-pin housings provide automatic alignment and me-

chanical stability when the avatar is placed onto the deck.

# 4.2.4 Avatar Identification Mechanism. To differentiate between

two physical avatar variants, we implemented a hardware-based

identification mechanism using distinct resistor configurations.

Each avatar contains a predefined resistor network connected to an

analog-to-digital converter (ADC) pin on the Raspberry Pi Pico mi-

crocontroller. Avatar 1 integrates two 20 kΩ resistors, while Avatar

2 uses one 20 kΩ and one 51 kΩ resistor. These differing resistor

combinations result in distinct measurable voltage levels at the

ADC input due to variations in current flow characteristics.

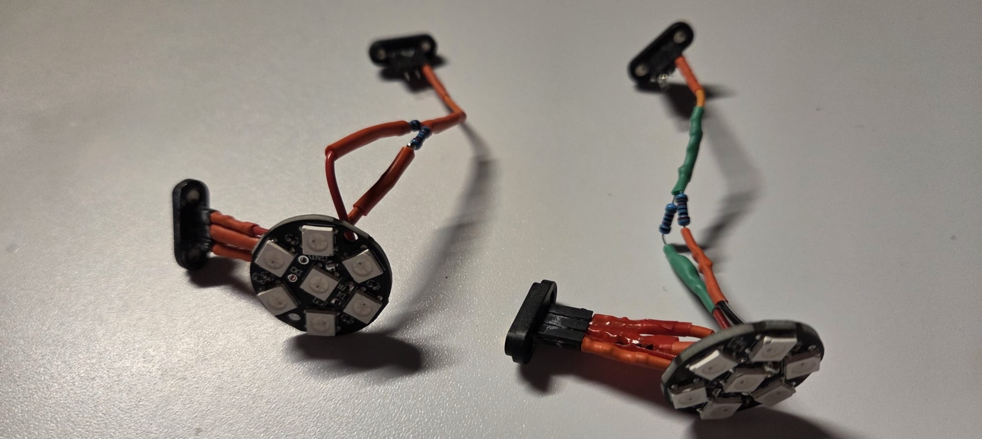
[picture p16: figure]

Figure 8: Internal hardware layout of both avatar variants,

including resistor configurations.

By reading the voltage value, the microcontroller can reliably

determine the connected avatar. This enables automatic avatar

recognition without additional digital communication interfaces,

reducing wiring complexity while ensuring reliable identification.

### 4.3 Software

The GitHub repository includes all software and hardware code,

along with all assets: https://github.com/simonroedig/PrivacyDeck

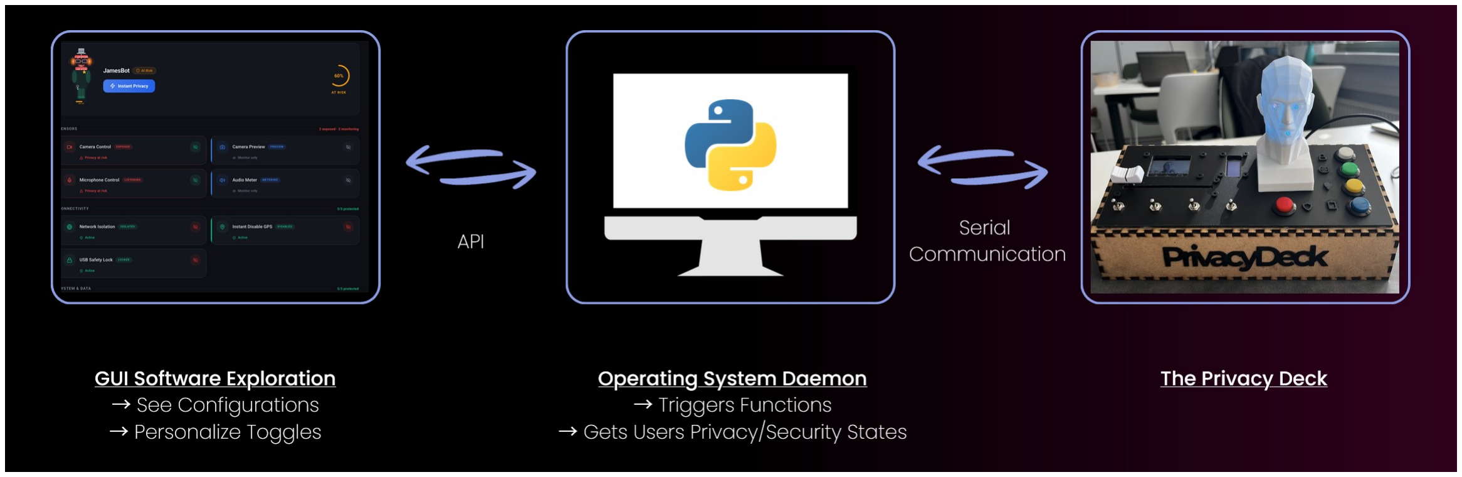
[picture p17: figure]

Figure 9: Overview of the PrivacyDeck architecture.

4.3.1 OS Daemon. The operating system integration of the Pri-

vacyDeck is handled by a lightweight Python-based daemon run-

ning on the host machine. Communication with the Raspberry

Pi Pico microcontroller occurs via a serial connection over USB.

The microcontroller transmits predefined command signals (e.g.,

LOCK_SYSTEM) which are parsed and executed by the daemon. This

serial communication approach proved reliable and responsive for

triggering discrete privacy-related actions such as locking the sys-

tem, muting the microphone, or toggling connectivity settings.

While serial transmission was sufficient for control signals, band-

width limitations appeared when integrating two SPI-connected

displays for live webcam and microphone activity. To offload contin-

uous data transfer, we implemented an alternative communication

path using WebSockets over a local network connection, enabling

stable real-time streaming for both webcam preview and audio

visualisation in controlled network environments.

The daemon was tested across Windows, Linux, and partially

macOS. Linux provided the most flexible integration, as privacy-

relevant system functions can be executed directly via shell scripts

with appropriate permissions; the final demonstration was therefore

conducted on Linux. Windows presented the greatest challenges:

several privacy functions, such as enabling airplane mode, are not

accessible through standard Python libraries or publicly exposed system APIs, requiring graphical automation workarounds that sim-

ulate keyboard navigation through settings menus. This approach

increases fragility due to UI dependency and makes reliable state

introspection difficult, as the system can often only toggle a setting

without robustly querying its current state.

These cross-platform inconsistencies highlight a broader in-

frastructural limitation: the absence of a unified, open, operating-

system-level API for privacy and security controls. Developing such

a standardised framework would significantly lower the barrier for

future tangible privacy interfaces, enabling reliable, cross-platform

access to system-level privacy functions without resorting to UI

automation or platform-specific workarounds.

# 4.3.2 GUI Implementation. The companion desktop dashboard was

developed as a standalone software to the physical deck. Its architec-

ture anticipates a three-layer design: a firmware layer (currently the

Raspberry Pi Pico communicating over serial USB, with a planned

migration to an ESP32 forwarding events over TCP) that captures

button events; the Python daemon that executes OS-level privacy

controls and maintains the canonical feature state; and the React

frontend that provides visualisation, interaction, and configuration.

State is managed through shared React contexts (PrivacyContext

and AvatarContext), providing a single source of truth; a dedi-

cated WebSocket hook handles the connection lifecycle, keeping

rendering concerns separated from daemon communication.

# Initial design and iterations. As a first step, several Figma screens

were developed and iteratively refined with the goal of maintaining

simplicity and intuitiveness by following the macOS layout con-

ventions. The process resulted in four final screens as the basis for

the accompanying desktop dashboard as shown in Figure 10.

# Privacy score and state feedback. As illustrated in Figure 11, pri-

vacy functions are organised into exposure controls (camera and

microphone), protection controls (network isolation, GPS, USB lock,

clipboard guard, and browser cleaning), and monitoring controls

(audio meter and camera preview). A composite privacy score is

computed in real time, weighted at 40 % for exposure safety and 60 %

for protection coverage. This reflects a deliberate design heuristic:

active sensors represent the most immediate vector for data leak-

age, whereas connectivity and data controls govern the potential

blast radius of any failure. The weights are not empirically derived;

they constitute an initial parameterisation open to future validation

through user studies.

Rather than presenting the score as an opaque scalar, the inter-

face exposes a live attribution panel that identifies which control

was toggled and whether the transition improved or worsened pri-

vacy posture. This is motivated by Lim et al. [11], who showed that

causal why and why-not explanations improve user understand-

ing of context-aware systems compared with state-only feedback.

An Instant Privacy button toggles every feature to its maximum

protective state simultanously in a single gesture, embodying Shnei-

derman’s principle of rapid operations on visible objects [17].

# Privacy Advisor: context-aware adaptive guidance. The score and attribution panel tell users where they stand, but not what to do

next. The Privacy Advisor, visible across all three panels of Fig-

ure 11, closes this awareness-to-action gap [1] by delivering context-

sensitive, single-sentence recommendations in real time.

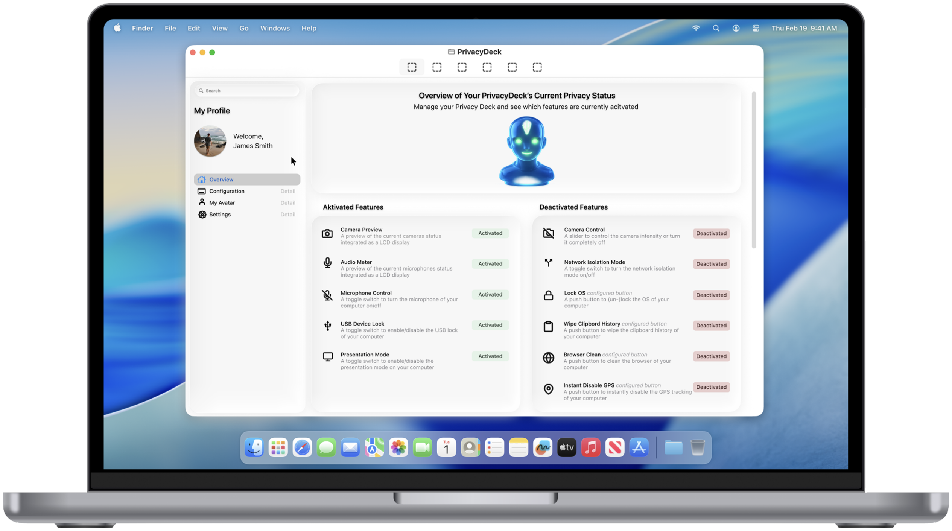
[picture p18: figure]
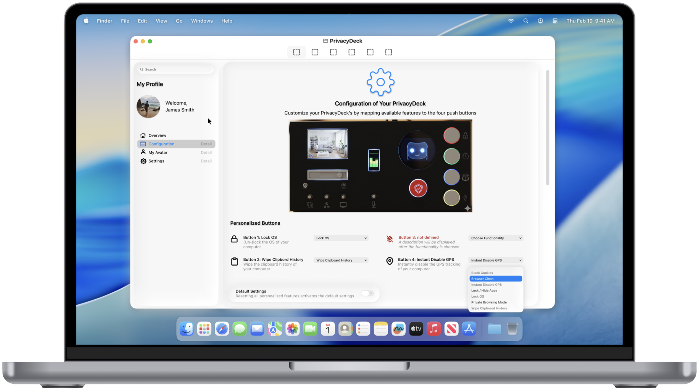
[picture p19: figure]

(a) Overview | (b) Configuration

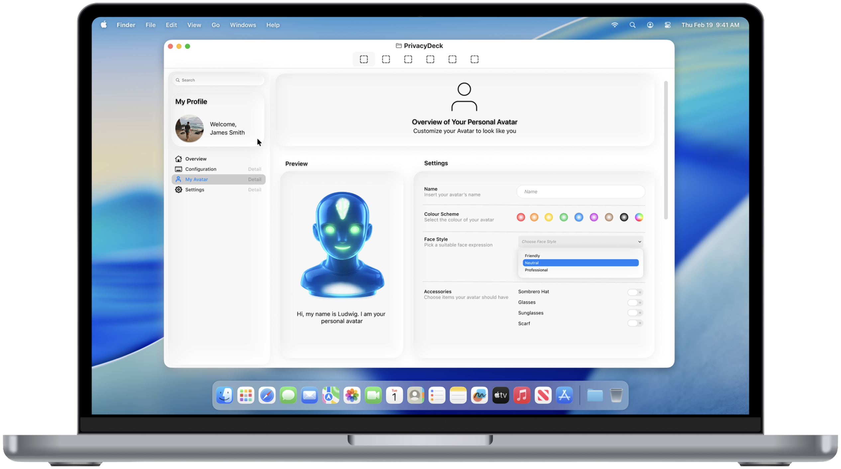
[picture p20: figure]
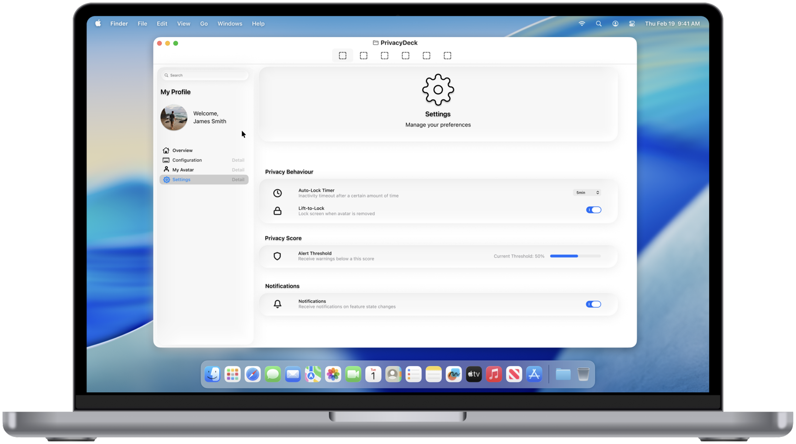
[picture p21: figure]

(c) My Avatar | (d) Settings

Figure 10: Final Figma screens for subpages.

Three HCI principles shape its design. First, following Horvitz’s

mixed-initiative framework [10], recommendations are presented

as dismissable, refreshable suggestions rather than modal interrup-

tions, preserving user control over attention allocation. Second,

drawing on digital nudge theory [19, 20], the advisor surfaces the

single most actionable risk at the moment a toggle changes, fram-

ing consequences in concrete terms rather than abstract threat

levels. Third, to ensure glanceability under divided attention, the

advisor surfaces exactly one recommendation per state change,

colour-coded to match the current risk tier.

Critically, the advisor is not a thin wrapper around a language

model. A four-stage local pipeline executes entirely in the browser

before any external call is made. First, a behavioural pattern analy-

sis flags habitual risks, features remaining in a risky state in at least

60 % of their last 20 recorded appearances, and computes a score

trend via split-half comparison, following the just-in-time adaptive

intervention principle that historical behaviour should inform the

timing and content of guidance [14]. Second, a state-diffing function

identifies the most recently changed feature within a three-second

recency window and classifies the action as secured or exposed.

Third, a builder function assembles all upstream signals as current

score, toggle classification, network trust status, habitual patterns,

and score trend, into a single priority-ranked payload encoding

domain-specific information triage. Only at the final stage is this compiled context forwarded to OpenAI’s Chat Completions API¹

(model gpt-4o-mini, 75-token cap), where a constrained system

prompt renders the pre-decided recommendation as a single per-

sonalised sentence. The language model thus functions as a text

rendering layer for decisions already made upstream. The orches-

trating hook adds debouncing (1 400 ms), state-key deduplication,

race-condition guards, and graceful degradation to locally gener-

ated fallback messages when the API is unreachable.

# Avatar customisation and peripheral feedback. Figure 12 shows

the customisation panel through which users configure body shape,

colour scheme, face style, and accessories. The configured avatar

persists across all dashboard states; its eye and mouth illumination

update continuously to reflect the current privacy score, keeping sta-

tus visible in the periphery without demanding active inspection—

consistent with Weiser and Brown’s calm-technology vision [21].

By granting users authorship over the avatar’s appearance, the

system creates a personally resonant reference point for privacy

posture. Birk et al. [4] demonstrated that avatar customisation

strengthens identification and intrinsic motivation, directly moti-

vating this design choice. Gamification signals such as vitality cues

further reinforce protective behaviour, calibrated so that a fully-

protected indication appears only when all controls are verifiably

1https://platform.openai.com/docs/api-reference/chat

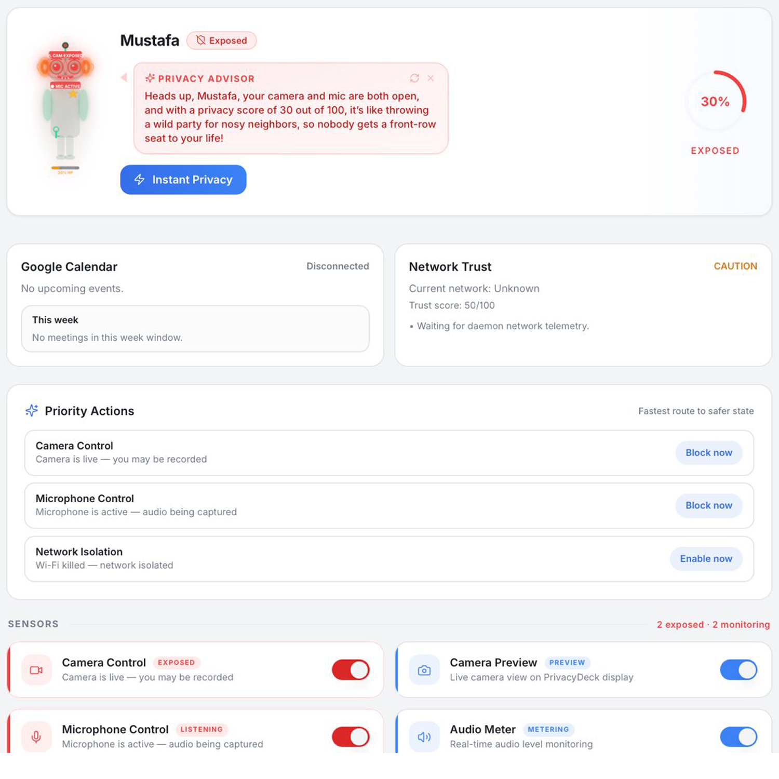
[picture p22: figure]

(a) camera and microphone active, score 30, Exposed.

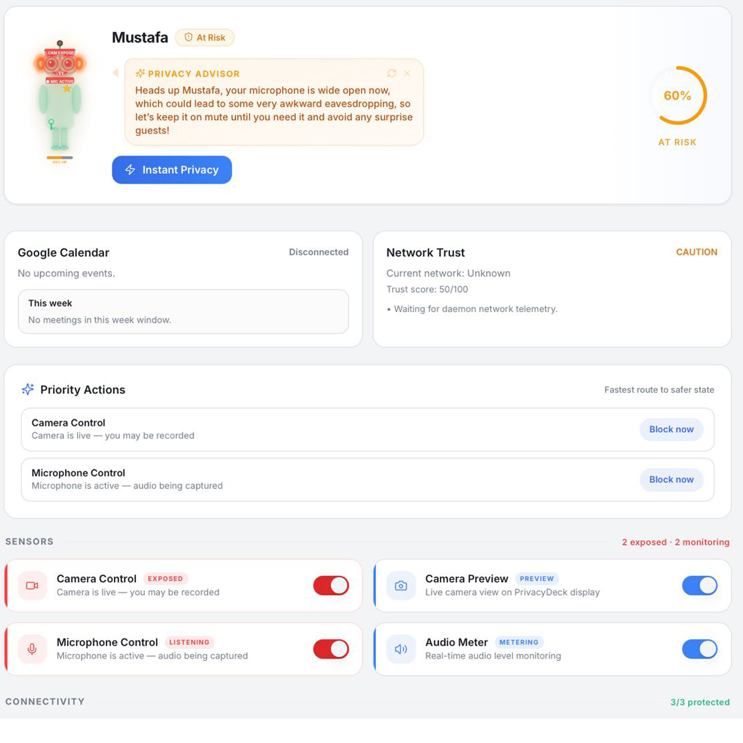
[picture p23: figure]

(b) microphone active, camera blocked, score 60, At Risk.

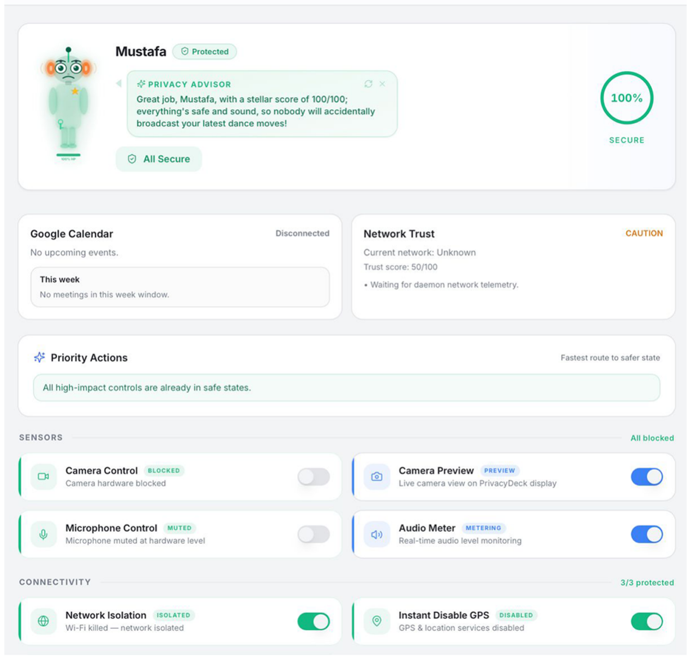
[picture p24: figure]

(c) all sensors blocked and all protections active, score 100, Secure.

Avatar expression, score-ring colour, and Privacy Advisor tone up-

date in real time.

Figure 11: The PrivacyDeck dashboard across three privacy

states.

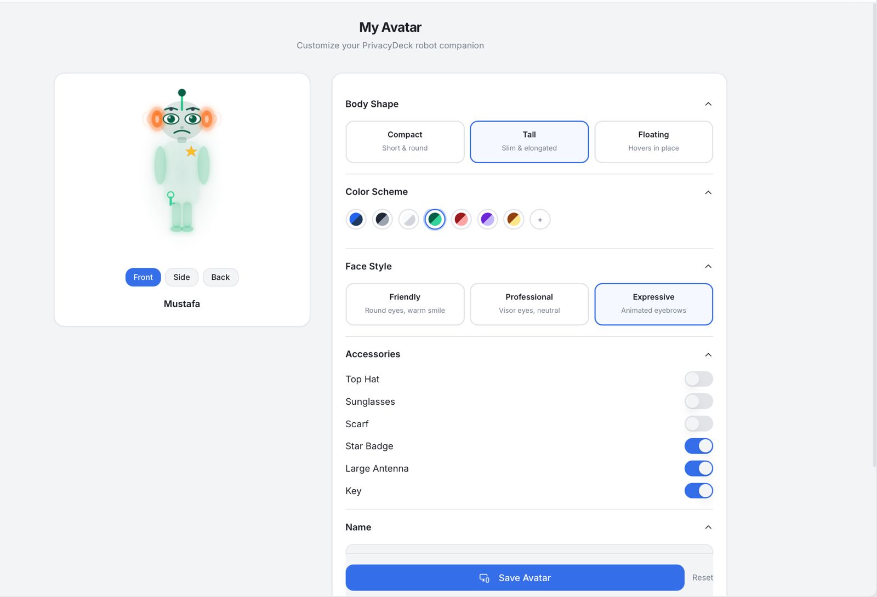
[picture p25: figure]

Figure 12: Avatar customisation panel of body shape, colour,

face style, and accessories across all dashboard states.

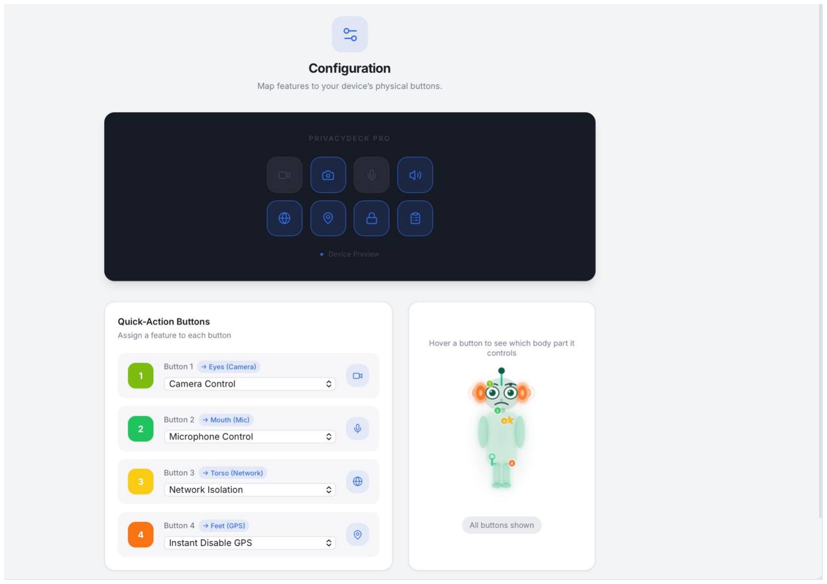
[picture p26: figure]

Figure 13: Configuration view for assigning privacy functions

to physical buttons.

safe, consistent with Fogg’s [8] principle that persuasive systems

must not mislead users about consequences.

# Button-mapping configuration. Figure 13 shows the view through

which users assign privacy functions to each of the eight physical

button slots. Hovering over a slot in the device preview highlights

the corresponding avatar body part, reinforcing the physical-to-

digital mapping before the user commits. All personalisation data

(avatar appearance, button mappings) is stored locally, ensuring

that no privacy-relevant configuration leaves the user’s machine.

### 5 Discussion

The PrivacyDeck illustrates a tangible approach to addressing the

core barriers identified in prior work: fragmented controls that

induce privacy fatigue [16], absent feedback that degrades situation

awareness under cognitive load [6], and ambiguous device states

that erode user trust [2]. By mapping each protective action to

a dedicated physical control, the system delivers immediate, low-

latency responses that bypass the software navigation overhead

Alashwali et al. [3] identified as a primary deterrent to consistent

privacy behaviour. Simultaneously, the avatar and hardware indi-

cators maintain continuous peripheral awareness, consistent with

Weiser and Brown’s calm-technology vision [21], addressing the

attentional limitations that Portnoff et al. [15] showed cause mo

even existing webcam LEDs to go unnoticed in 95 % of cases when

user attention is directed elsewhere. Our modular avatar extends

prior tangible prototypes such as PriviFy [13] beyond IoT config-

uration into desktop privacy management, integrating real-time

sensor state into a personalisable ambient display that leverages

identification effects observed by Birk et al. [4].

Several limitations bound our current contribution. Cross- plat-

form testing indicated reliable operation on Linux but exposed

significant limitations on Windows, where the absence of publicly

exposed privacy APIs necessitated brittle UI automation. This un-

derscores a broader infrastructural gap: without a unified, open

framework for privacy controls, tangible privacy interfaces remain

constrained by platform-specific affordances. We propose a secure,

standardized Open Privacy Control API to abstract OS-level privacy

functions into a unified, cross-platform interface. This is challeng-

ing, because it needs consensus among proprietary OS vendors, but

we believe defining such an open standard is a necessary prerequi-

site for the future development of scalable, trusted, and low-friction

physical privacy tools. Furthermore the prototype has not been

evaluated with end users; quantitative impacts on privacy fatigue

and behavioural consistency remain open for controlled studies.

The privacy score weighting (40 % exposure, 60 % protection) is a

design heuristic, not an empirically calibrated metric. The Instant

Privacy button currently prioritises speed over reversibility; future

iterations should incorporate a brief undo window or confirma-

tion gate to prevent disruptive accidental activation during live

sessions such as video calls. Finally, the Privacy Advisor’s reliance

on an external language model introduces a latency and availabil-

ity dependency; moreover, forwarding compiled recommendation

context to an external provider represents a privacy tradeoff that

future iterations should resolve through fully local generation.

### 6 Conclusion

PrivacyDeck provides a tangible solution that externalises high-

frequency privacy actions into persistent physical controls with

real-time, interpretable feedback. By reducing interaction friction

and supporting situation awareness [6], the device aims to help

users protect their desktop environments more consistently and

confidently. This work underscores the value of physical comput-

ing for usable security and privacy, and advocates for an open,

cross-platform API to support seamless integration of system-level

privacy tools. Future iterations should incorporate formal user

evaluations, expand hardware modularity, and explore adaptive

feedback mechanisms that respond to individual risk profiles over

time.

### Acknowledgments

The authors used large language models (ChatGPT, Grok) as edito-

rial tools during the revision process. All research design, system

implementation, analysis, and argumentation are entirely the au-

thors’ own work.

### References

[1] Alessandro Acquisti, Idris Adjerid, Rebecca Balebako, Laura Brandimarte, Lor-

rie Faith Cranor, Saranga Komanduri, Pedro Giovanni Leon, Norman Sadeh,

Florian Schaub, Manya Sleeper, et al. 2017. Nudges for privacy and security:

Understanding and assisting users’ choices online. ACM Computing Surveys

(CSUR) 50, 3 (2017), 1–41.

[2] Imtiaz Ahmad, Rosta Farzan, Apu Kapadia, and Adam J. Lee. 2020. Tangible

Privacy: Towards User-Centric Sensor Designs for Bystander Privacy. Proc. ACM

Hum.-Comput. Interact. 4, CSCW2, Article 116 (Oct. 2020), 28 pages. doi:10.1145/

3415187 (https://doi.org/10.1145/3415187)

[3] Eman Alashwali, Joanne Peca, Mandy Lanyon, and Lorrie Faith Cranor. 2025.

Work from home and privacy challenges: what do workers face and what are

## they doing about it? Journal of Cybersecurity 11, 1 (2025), tyaf010. doi:10.1093/

cybsec/tyaf010 (https://doi.org/10.1093/cybsec/tyaf010)

[4] Max V. Birk, Cheralyn Atkins, Jamie T. Bowey, and Regan L. Mandryk. 2016.

Fostering Intrinsic Motivation through Avatar Identification in Digital Games.

## In Proceedings of the SIGCHI Conference on Human Factors in Computing Systems

(CHI ’16). Association for Computing Machinery, 2982–2995. doi:10.1145/2858036.

2858062 (https://doi.org/10.1145/2858036.2858062)

[5] Sarah Delgado Rodriguez, Anh Dao Phuong, Franziska Bumiller, Lukas Mecke,

Felix Dietz, Florian Alt, and Mariam Hassib. 2023. Padlock, the Universal Se-

curity Symbol? - Exploring Symbols and Metaphors for Privacy and Security.

## In Proceedings of the 22nd International Conference on Mobile and Ubiquitous

Multimedia (Vienna, Austria) (MUM ’23). Association for Computing Machinery,

New York, NY, USA, 10–24. doi:10.1145/3626705.3627770 (https://doi.org/10.1145/3626705.3627770)

[6] Mica R Endsley. 1995. Toward a Theory of Situation Awareness in Dynamic

## Systems. Human Factors: The Journal of the Human Factors and Ergonomics

Society 37, 1 (1995), 32–64.

[7] Florian M. Farke, David G. Balash, Maximilian Golla, Markus Dürmuth, and

Adam J. Aviv. 2021. Are Privacy Dashboards Good for End Users? Evaluating

User Perceptions and Reactions to Google’s My Activity. In 30th USENIX Security
Symposium (USENIX Security 21). USENIX Association, 483–500. https://www.

usenix.org/conference/usenixsecurity21/presentation/farke

## [8] Brian J. Fogg. 2003. Persuasive Technology: Using Computers to Change What We

Think and Do. Morgan Kaufmann, San Francisco, CA.

[9] Hana Habib, Yixin Zou, Yaxing Yao, Alessandro Acquisti, Lorrie Cranor, Joel

Reidenberg, Norman Sadeh, and Florian Schaub. 2021. Toggles, Dollar Signs, and

Triangles: How to (In)Effectively Convey Privacy Choices with Icons and Link

## Texts. In Proceedings of the 2021 CHI Conference on Human Factors in Computing

Systems (Yokohama, Japan) (CHI ’21). Association for Computing Machinery,

New York, NY, USA, Article 63, 25 pages. doi:10.1145/3411764.3445387 (https://doi.org/10.1145/3411764.3445387)

[10] Eric Horvitz. 1999. Principles of mixed-initiative user interfaces. In Proceedings
of the SIGCHI Conference on Human Factors in Computing Systems (Pittsburgh,

Pennsylvania, USA) (CHI ’99). Association for Computing Machinery, New York,

NY, USA, 159–166. doi:10.1145/302979.303030 (https://doi.org/10.1145/302979.303030)

[11] Brian Y. Lim, Anind K. Dey, and Daniel Avrahami. 2009. Why and Why Not

Explanations Improve the Intelligibility of Context-Aware Intelligent Systems.

## In Proceedings of the SIGCHI Conference on Human Factors in Computing Systems

(CHI ’09). Association for Computing Machinery, 2119–2128. doi:10.1145/1518701.

1519023 (https://doi.org/10.1145/1518701.1519023)

[12] Vikram Mehta, Daniel Gooch, Arosha Bandara, Blaine Price, and Bashar Nuseibeh.

2021. Privacy Care: A Tangible Interaction Framework for Privacy Management.
ACM Trans. Internet Technol. 21, 1, Article 25 (2021). doi:10.1145/3430506 (https://doi.org/10.1145/3430506)
[13] Bayan | Al Muhander, Omer | Rana, and Charith Perera. | 2024. | PriviFy:
Designing Tangible | Interfaces | for | Configuring IoT Privacy Preferences.

arXiv:2406.05459 [cs.CR] https://arxiv.org/abs/2406.05459

[14] Inbal Nahum-Shani, Shawna N Smith, Bonnie J Spring, Linda M Collins, Katie

Witkiewitz, Ambuj Tewari, and Susan A Murphy. 2016. Just-in-time adaptive

interventions (JITAIs) in mobile health: key components and design principles
for ongoing health behavior support. Annals of behavioral medicine (2016), 1–17.
[15] Rebecca S. Portnoff, Linda N. Lee, Serge Egelman, Pratyush Mishra, Derek Leung,

and David Wagner. 2015. Somebody’s Watching Me? Assessing the Effectiveness

## of Webcam Indicator Lights. In Proceedings of the 33rd Annual ACM Conference

on Human Factors in Computing Systems (Seoul, Republic of Korea) (CHI ’15).

Association for Computing Machinery, New York, NY, USA, 1649–1658. doi:10.

1145/2702123.2702164 (https://doi.org/10.1145/2702123.2702164)

[16] Han Shao, Xiang Li, and Guodi Wang. 2022. Are You Tired? I am: Trying to

Understand Privacy Fatigue of Social Media Users. In Extended Abstracts of the
2022 CHI Conference on Human Factors in Computing Systems (New Orleans, LA,

USA) (CHI EA ’22). Association for Computing Machinery, New York, NY, USA,

Article 378, 7 pages. doi:10.1145/3491101.3519778 (https://doi.org/10.1145/3491101.3519778)

[17] Ben Shneiderman. 1983. Direct Manipulation: A Step Beyond Programming

Languages. Computer 16, 8 (1983), 57–69. doi:10.1109/MC.1983.1654471 (https://doi.org/10.1109/MC.1983.1654471)

[18] Yunpeng Song, Cori Faklaris, Zhongmin Cai, Jason I. Hong, and Laura Dabbish.

2019. Normal and Easy: Account Sharing Practices in the Workplace. Proc. ACM

## Hum.-Comput. Interact. 3, CSCW, Article 83 (Nov. 2019), 25 pages. doi:10.1145/

3359185 (https://doi.org/10.1145/3359185)

## [19] Richard H. Thaler and Cass R. Sunstein. 2008. Nudge: Improving Decisions About

Health, Wealth, and Happiness. Yale University Press, New Haven, CT.

[20] Markus Weinmann, Christoph Schneider, and Jan vom Brocke. 2016. Digital
nudging. Business & Information Systems Engineering 58, 6 (2016), 433–436.

[21] Mark Weiser and John Seely Brown. 1996. Designing Calm Technology. Power-
Grid Journal 1, 1 (1996), 75–85.

### Character Count

This work contains 29393 characters (without spaces).

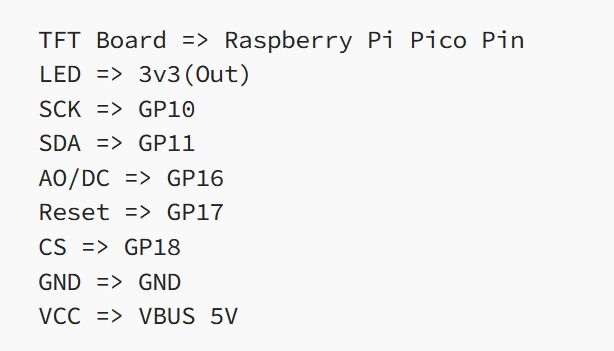
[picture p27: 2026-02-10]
exploration/Test_BigTFTDisplay/pinout.jpeg

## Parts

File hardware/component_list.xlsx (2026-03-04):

Quantity | Component | Link (Reichelt || Conrad || Eckstein) | Price Single (€) | Price TOTAL (€) | (Notes)
2 | LED Jewel 7 x 5050 RGB LEDs WS2812 | https://eckstein-shop.de/LEDJewel7x5050RGBLEDsWS2812mitintegriertenTreibern | 1.91 | 3.82 | LED
2 | Kodierter Drehschalter | https://www.reichelt.de/de/de/shop/produkt/entwicklerboards_-_kodierter_drehschalter-239260 | 2.5 | 5 | Rotary Knob
2 | Kontermutter für Potentiometerknöpfe, schwarz | https://www.reichelt.de/de/de/shop/produkt/kontermutter_fuer_potentiometerknoepfe_schwarz-13757 | 0.22 | 0.44 | for Rotary Knob
1 | Developer boards - Sliding potentiometer, 10k Ohm | https://www.reichelt.com/de/en/shop/product/developer_boards_-_sliding_potentiometer_10k_ohm-375945 | 2.6 | 2.6 | Fader/Slider -> search for alternative
1 | Seeed Studio Grove Slide Potentiometer with 10KΩ Resistance | https://eckstein-shop.de/Seeed-Studio-Grove-Slide-Potentiometer-with-10KO-Resistance | 7.14 | 7.14 | need both now
2 | Schalterkappe | https://www.reichelt.de/de/de/shop/produkt/schalterkappe_16_8_mm_6_mm-227904 | 0.8 | 1.6 | for Rotary Knob
4 | Toggle Switch | https://eckstein-shop.de/PololuToggleSwitch3A3-Pin2CSPDT2C5AEN | 1.64 | 6.56 | Toggle
1 | WaveShare 160x80, General 0.96inch LCD display Module, IPS, HD | https://eckstein-shop.de/WaveShare-160x80-General-096inch-LCD-display-Module-IPS-HD | 6.99 | 6.99 | 1,08 cm × 2,17 cm
1 | WaveShare 2inch LCD Display Module 240x320 IPS Screen SPI Interface | https://eckstein-shop.de/WaveShare-240320-General-2inch-IPS-LCD-Display-Module | 11.99 | 11.99 | 30,60 mm × 40,80 mm
1 | Rugged Metal Pushbutton with Red LED Ring - 16mm Red Momentary | https://eckstein-shop.de/RuggedMetalPushbuttonwithRedLEDRing-16mmRedMomentaryEN | 2.93 | 2.93 | rot (clipboard)
1 | Rugged Metal Pushbutton with Red LED Ring - 16mm Blue Momentary | https://eckstein-shop.de/QITARuggedMetalPushbuttonwithBlueLEDRing-16mmBlueMomentaryEN | 2.93 | 2.93 | blau (location)
1 | Rugged Metal Pushbutton with Red LED Ring - 16mm Yellow Momentary | https://eckstein-shop.de/RuggedMetalPushbuttonwithYellowLEDRing-16mmYellowMomentaryEN | 2.82 | 2.82 | gelb (browser cookies)
1 | Rugged Metal Pushbutton with White LED Ring - 16mm White Momentary | https://eckstein-shop.de/QITARuggedMetalPushbuttonwithWhiteLEDRing-16mmWhiteMomentaryEN | 2.93 | 2.93 | weiß (lock os)
1 | Raspberry Pi Pico 2 WH, RP235x, Cortex-M33, WiFi, microUSB | https://www.reichelt.com/de/en/shop/product/raspberry_pi_pico_2_wh_rp235x_cortex-m33_wifi_microusb-398576 | 8.5 | 8.5 | better microcontroller for our needs
1 | Joy-it COM-MSD Erweiterungsmodul | https://www.conrad.de/de/p/joy-it-com-msd-erweiterungsmodul-1-st-2582441.html | 2.9 | 2.9 | sd
10 | Lichtleiter | https://www.reichelt.de/de/de/shop/produkt/lichtleiter_smd_1-fach_o_2_2_mm_sphaerisch_flexibel-232128 | 0.99 | 9.9 | for led in avatar
1 | Drucktaster zum Einbau 12 mm 2 x Schraubklemme rot | https://www.reichelt.de/de/de/shop/produkt/drucktaster_zum_einbau_12_mm_2_x_schraubklemme_rot-411461 | 3.9 | 3.9 | Instant Privacy
 |  |  | Sum: | 82.95

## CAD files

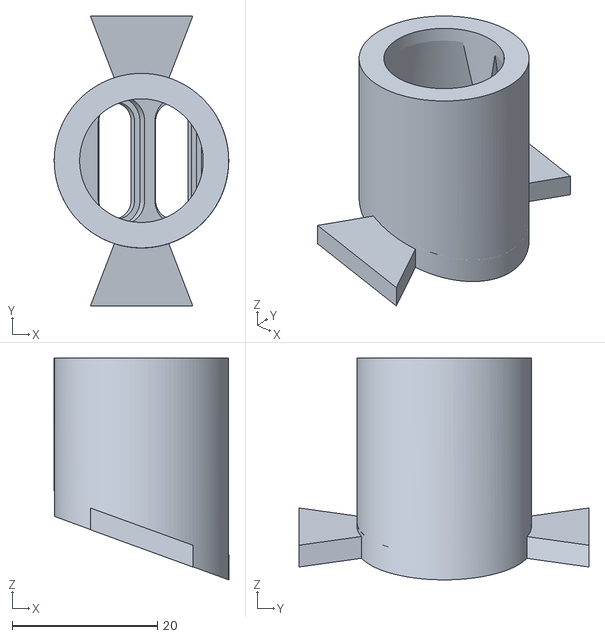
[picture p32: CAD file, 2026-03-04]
3d/avatar/AvatarInsert.stl
24.0 x 39.9 x 30.5

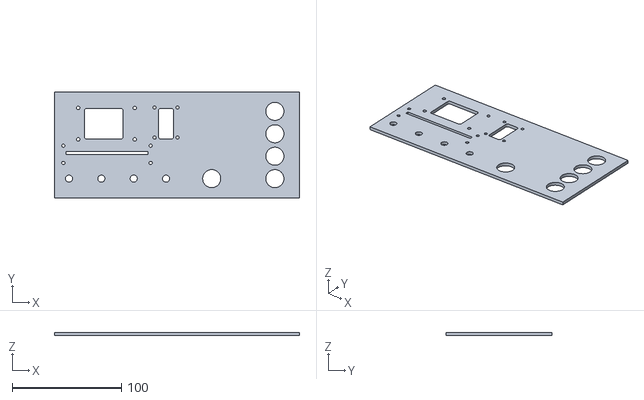
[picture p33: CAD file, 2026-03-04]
lasercut/PrivacyDeckTop.stl
224.0 x 97.0 x 3.00

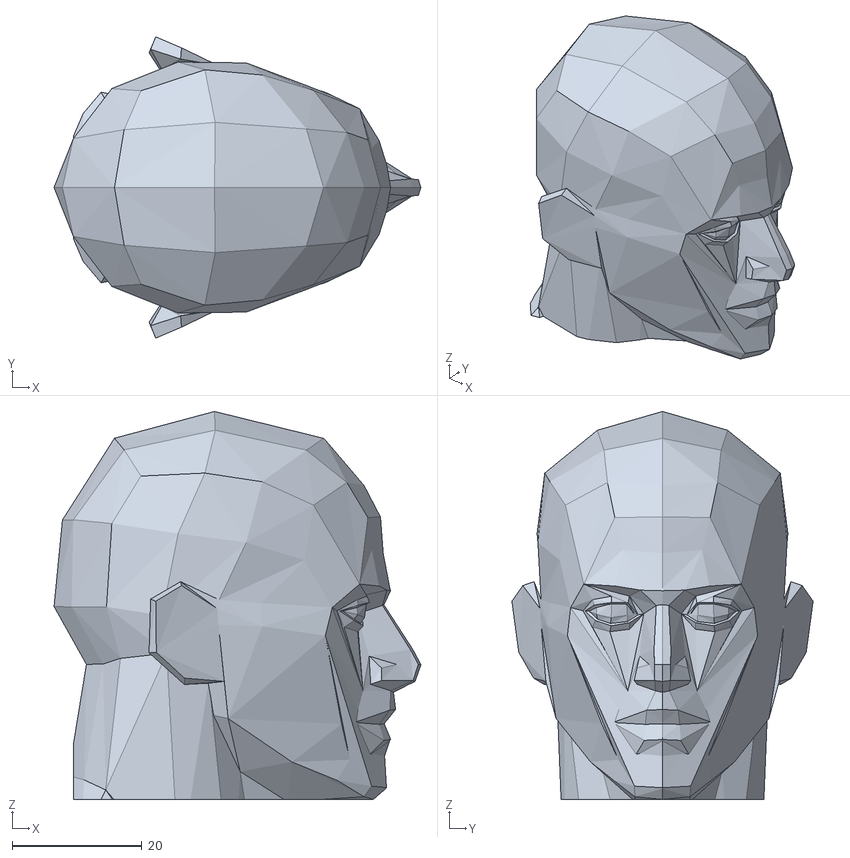
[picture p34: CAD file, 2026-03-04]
3d/avatar/AvatarHead.stl
56.6 x 46.5 x 59.9

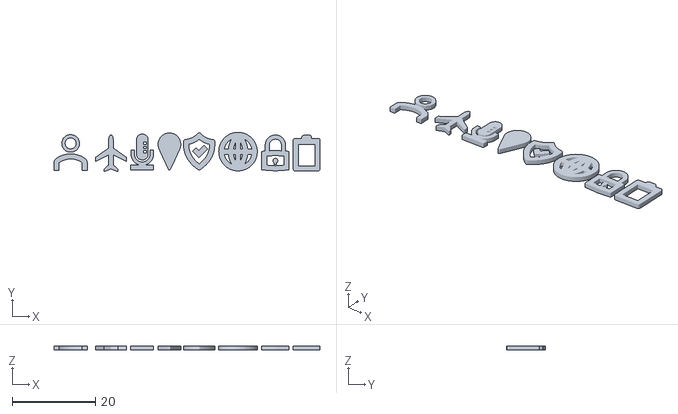
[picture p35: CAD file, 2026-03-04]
3d/Icons.stl
64.1 x 9.49 x 1.01

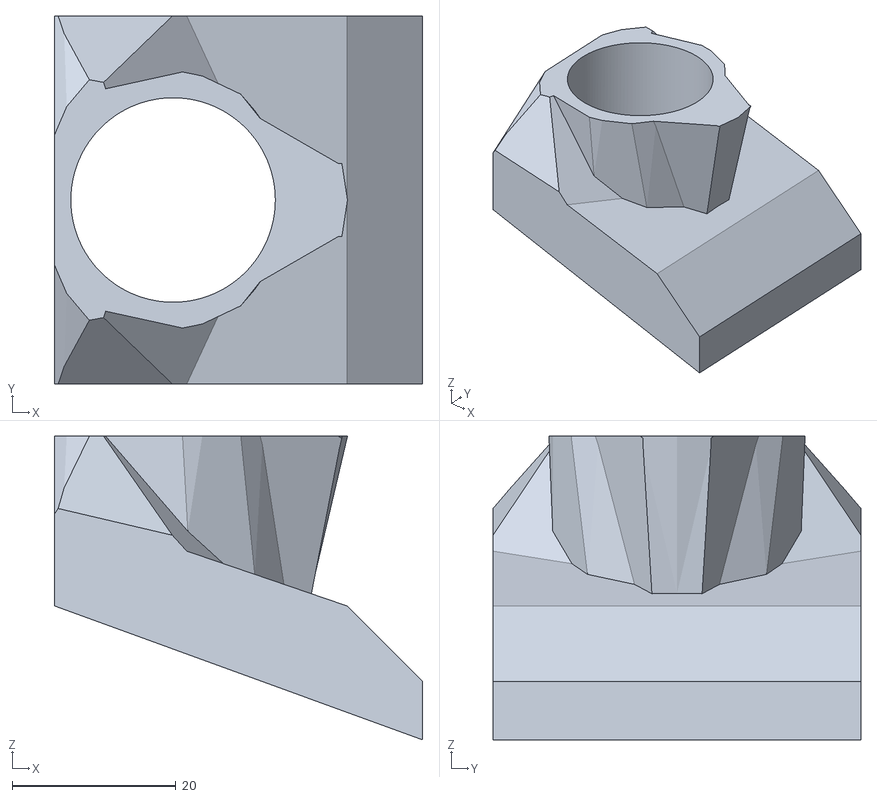
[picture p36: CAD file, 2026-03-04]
3d/avatar/AvatarBase.stl
45.0 x 45.0 x 37.1

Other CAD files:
3d/Fonts.stl

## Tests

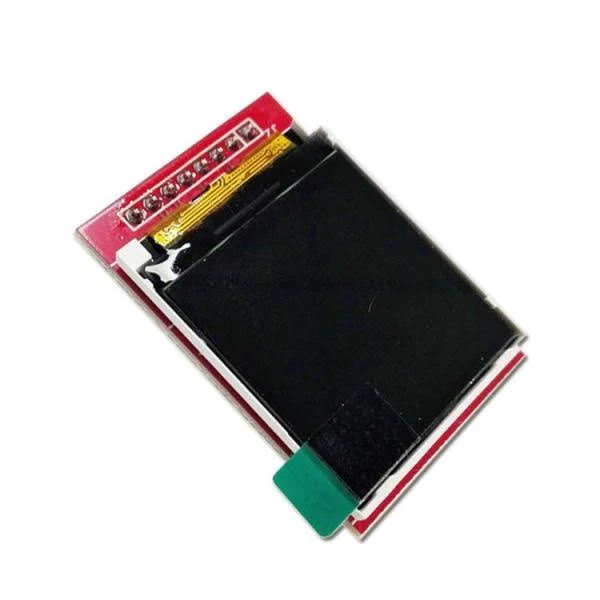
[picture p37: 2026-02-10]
exploration/Test_BigTFTDisplay/reference.png

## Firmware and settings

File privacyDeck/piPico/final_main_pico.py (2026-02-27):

import machine
from machine import Pin, ADC, SPI
import time
import json
import neopixel
import ST7735
import math
import random

# --- Color Definitions (RGB565) ---
RED = 0xF800
GREEN = 0x07E0
BLUE = 0x001F
YELLOW = 0xFFE0
BLACK = 0x0000
WHITE = 0xFFFF

# ==========================================
# MACRO PAD CONFIGURATION
# ==========================================
BUTTONS = {
    0: {"name": "Button 1", "func": "Lock OS"},
    1: {"name": "Button 2", "func": "browser clean"},
    2: {"name": "Button 3", "func": "gps mode"},
    3: {"name": "Button 4", "func": "wipe clipboard history"},
    4: {"name": "Button 5", "func": "Instant Privacy"}
}

TOGGLES = {
    5: {"name": "Toggle 1", "func": "usb alert"},
    6: {"name": "Toggle 2", "func": "blackout/presentation mode"},
    7: {"name": "Toggle 3", "func": "airplane mode"},
    8: {"name": "Toggle 4", "func": "mic mute toggle"}
}

DEBOUNCE_DELAY = 50

# ==========================================
#Slider Configuration
# ==========================================

slider = ADC(27)
last_slider_value = -1

# ==========================================
# AVATAR CONFIGURATION
# ==========================================
NUM_LEDS = 7
NEO_PIN = 28
ADC_PIN = 26

# Thresholds for Avatar Recognition
NO_AVATAR_MAX = 0.9
AV1_47K_MIN = 0.95
AV1_47K_MAX = 1.2
AV2_20K_MIN = 1.5
AV2_20K_MAX = 1.7  # leave headroom below 3.3 V

AVATAR_LED_MAP = {
    "head": [2, 3, 5, 6],
    "eyes": [1, 4],
    "mouth": [0]
}

active_pulsing_parts = {}
last_pulse_update = 0
pulse_angle = 0.0
PULSE_INTERVAL = 30  # Milliseconds between updates (approx 33 fps)
PULSE_SPEED = 0.1  # How much the angle increments per frame

COLOR_OFF = (0, 0, 0)
COLOR_AV1 = (0, 100, 225)  # blue
COLOR_AV2 = (255, 100, 0)  # yellow
RGB_WHITE = (255, 255, 255)
RGB_RED = (255, 0, 0)
RGB_GREEN = (0, 255, 0)
RGB_BLUE = (0, 0, 255)
RGB_YELLOW = (255, 255, 0)

# --- FADE CONFIGURATION ---
fade_start_time = 0
is_fading = False
fade_duration = 3000
current_base_head_color = COLOR_OFF

# ==========================================
# SPI Display 1 (Red / Webcam)
# ==========================================
spi1 = SPI(1, baudrate=20_000_000, polarity=0, phase=0, sck=Pin(10), mosi=Pin(11))
cs1 = Pin(9, Pin.OUT)
dc1 = Pin(12, Pin.OUT)
rst1 = Pin(13, Pin.OUT)

display1 = ST7735.TFT(spi1, dc1, rst1, cs1)
display1.initr()

# ==========================================
# DISPLAY 2 (Blue / Mic - 160x80) - SPI0
# ==========================================
spi0 = SPI(0, baudrate=20_000_000, polarity=0, phase=0, sck=Pin(18), mosi=Pin(19))
cs2 = Pin(17, Pin.OUT)
dc2 = Pin(20, Pin.OUT)
rst2 = Pin(21, Pin.OUT)

display2 = ST7735.TFT(spi0, dc2, rst2, cs2)
display2.initr()
display1.fill(BLACK)
display2.fill(BLACK)

# ==========================================
# AUDIO METER CONFIGURATION (DISPLAY 2) - PORTRAIT
# ==========================================
METER_COLS = 12
METER_ROWS = 16
COL_WIDTH = 8
COL_SPACING = 2
ROW_HEIGHT = 6
ROW_SPACING = 2
METER_UPDATE_INTERVAL = 60

# If the display leaves a gap on the side, adjust this offset (commonly 24 or 26 for 80x160 screens)
METER_X_OFFSET = 0
METER_Y_OFFSET = 0

# FIXED: Using 16-bit RGB565 integers instead of tuples
METER_COLORS = [WHITE] * 14 + [RED] * 2

meter_state = [0] * METER_COLS
last_meter_update = 0
meter_is_cleared = False

# ==========================================
# HELPER FUNCTIONS
# ==========================================
def custom_fill_rect(spi_bus, dc, cs, x, y, w, h, color):
    """Raw SPI rectangle drawing to bypass missing library methods."""
    x0, x1 = x, x + w - 1
    y0, y1 = y, y + h - 1

    cs.value(0)

    # Set Column Address
    dc.value(0)
    spi_bus.write(b'\x2A')
    dc.value(1)
    spi_bus.write(bytearray([0, x0, 0, x1]))

    # Set Row Address
    dc.value(0)
    spi_bus.write(b'\x2B')
    dc.value(1)
    spi_bus.write(bytearray([0, y0, 0, y1]))

    # Memory Write
    dc.value(0)
    spi_bus.write(b'\x2C')
    dc.value(1)

    # Prepare and send color buffer
    color_high = color >> 8
    color_low = color & 0xFF

    buf = bytearray([color_high, color_low] * (w * h))

    spi_bus.write(buf)
    cs.value(1)


def update_audio_meter(avatar_state):
    """Generates a bouncing audio matrix effect on Display 2."""
    global last_meter_update, meter_state, meter_is_cleared

    # Check Toggle 4 (Mic Mute). If it is in state '1' (Muted), hide the meter.
    if button_states_new.get("Toggle 4", 0) == 0 or avatar_state == "none":
        if not meter_is_cleared:
            display2.fill(BLACK)
            meter_state = [0] * METER_COLS
            meter_is_cleared = True
        return

    meter_is_cleared = False

    current_time = time.ticks_ms()
    if time.ticks_diff(current_time, last_meter_update) < METER_UPDATE_INTERVAL:
        return

    for col in range(METER_COLS):
        old_val = meter_state[col]

        # Randomly change the level
        change = random.randint(-4, 4)
        new_val = old_val + change

        if new_val < 0: new_val = 0
        if new_val > METER_ROWS: new_val = METER_ROWS

        if new_val > old_val:
            for r in range(old_val, new_val):
                # Inverted calculation: Starts at 0 and builds up
                y = METER_Y_OFFSET + r * (ROW_HEIGHT + ROW_SPACING) + ROW_SPACING
                x = METER_X_OFFSET + col * (COL_WIDTH + COL_SPACING) + (COL_SPACING // 2)
                custom_fill_rect(spi0, dc2, cs2, x, y, COL_WIDTH, ROW_HEIGHT, METER_COLORS[r])
        elif new_val < old_val:
            for r in range(new_val, old_val):
                y = METER_Y_OFFSET + r * (ROW_HEIGHT + ROW_SPACING) + ROW_SPACING
                x = METER_X_OFFSET + col * (COL_WIDTH + COL_SPACING) + (COL_SPACING // 2)
                custom_fill_rect(spi0, dc2, cs2, x, y, COL_WIDTH, ROW_HEIGHT, BLACK)

        meter_state[col] = new_val

    last_meter_update = current_time

def interpolate_color(color_start, color_end, elapsed, duration):
    """Calculates the intermediate color using safe integer math."""
    r = color_start[0] + (color_end[0] - color_start[0]) * elapsed // duration
    g = color_start[1] + (color_end[1] - color_start[1]) * elapsed // duration
    b = color_start[2] + (color_end[2] - color_start[2]) * elapsed // duration
    return (r, g, b)


def draw_bmp_to_display1(filename):
    print(f"Loading {filename}...")
    try:
        f = open(filename, "rb")
    except OSError:
        print(f"Error: {filename} not found on the Pico!")
        return

    # 1. Parse BMP Header
    header = f.read(54)
    if header[0:2] != b'BM':
        print("Error: Not a valid BMP file.")
        f.close()
        return

    data_offset = int.from_bytes(header[10:14], 'little')
    width = int.from_bytes(header[18:22], 'little')
    height_bytes = header[22:26]
    height = int.from_bytes(height_bytes, 'little')

    # Negative height means top-down image
    top_down = False
    if height > 0x7FFFFFFF:
        height = 0x100000000 - height
        top_down = True

    bpp = int.from_bytes(header[28:30], 'little')
    if bpp not in (16, 24):
        print(f"Error: Unsupported depth ({bpp}bpp). Please use a 24-bit BMP.")
        f.close()
        return

    print(f"Processing Image: {width}x{height} @ {bpp}bpp")

    row_bytes = ((width * bpp + 31) // 32) * 4
    f.seek(data_offset)

    # 2. Allocate memory buffer for the physical portrait display (128x160)
    # The Pi Pico has enough RAM to hold this entirely in memory for a fast SPI upload
    buf = bytearray(128 * 160 * 2)

    # 3. Read image, convert colors to 16-bit RGB565, and rotate it 90 degrees
    #    so that your horizontal 160x128 image fits the 128x160 physical layout.
    for r in range(height):
        # BMP rows are bottom-to-top by default
        r_mapped = (127 - r) if top_down else r

        row_data = f.read(row_bytes)

        # Prevent overflowing buffer if image is slightly larger
        if r_mapped >= 128: continue

        for c in range(width):
            if c >= 160: continue

            if bpp == 24:
                # 24-bit (Blue, Green, Red)
                b = row_data[c * 3]
                g = row_data[c * 3 + 1]
                r_col = row_data[c * 3 + 2]
                color = ((r_col & 0xF8) << 8) | ((g & 0xFC) << 3) | (b >> 3)
            else:
                # 16-bit BMP native
                color = row_data[c * 2] | (row_data[c * 2 + 1] << 8)

            # Map 160x128 Landscape to 128x160 Portrait Array
            idx = (c * 128 + r_mapped) * 2
            buf[idx] = color >> 8
            buf[idx + 1] = color & 0xFF

    f.close()

    print("Uploading to Red Webcam Screen via Fast SPI...")

    # 4. Use raw SPI commands to define screen writing area (X:0-127, Y:0-159)
    x0, x1 = 0, 127
    y0, y1 = 0, 159

    cs1.value(0)

    # CASET (Set Column Address)
    dc1.value(0)
    spi1.write(b'\x2A')
    dc1.value(1)
    spi1.write(bytearray([0, x0, 0, x1]))

    # RASET (Set Row Address)
    dc1.value(0)
    spi1.write(b'\x2B')
    dc1.value(1)
    spi1.write(bytearray([0, y0, 0, y1]))

    # RAMWR (Memory Write)
    dc1.value(0)
    spi1.write(b'\x2C')
    dc1.value(1)

    # 5. Blast the entire rotated image frame into the screen!
    spi1.write(buf)
    cs1.value(1)

    print("Image displayed successfully!")


def draw_bin(display, filename):
    """Streams a raw RGB565 .bin file to the display"""
    try:
        # Set the drawing window to full screen (128x160)
        display.setAddrWindow(0, 0, 127, 159)
        with open(filename, "rb") as f:
            chunk = f.read(2048)
            while chunk:
                display.data(chunk)
                chunk = f.read(2048)
    except Exception:
        display.fill(RED)  # Fallback if file is missing


def set_color(led_mapping):
    for led_index, color in led_mapping.items():
        np[led_index] = color
    np.write()


def update_pulsing():
    global last_pulse_update, pulse_angle

    if not active_pulsing_parts:
        return

    current_time = time.ticks_ms()

    # Throttle the LED updates to prevent protocol jamming
    if time.ticks_diff(current_time, last_pulse_update) >= PULSE_INTERVAL:

        # Increment the angle and wrap it at 2*Pi to prevent float overflow
        pulse_angle += PULSE_SPEED
        if pulse_angle > math.pi * 2:
            pulse_angle -= math.pi * 2

        # Calculate brightness: maps -1.0 to 1.0 sine wave to 0.5 to 1.0 multiplier
        wave = math.sin(pulse_angle)
        brightness = 0.75 + (wave * 0.25)

        for part, base_color in active_pulsing_parts.items():
            indices = AVATAR_LED_MAP[part]
            r = int(base_color[0] * brightness)
            g = int(base_color[1] * brightness)
            b = int(base_color[2] * brightness)

            for i in indices:
                np[i] = (r, g, b)

        np.write()
        last_pulse_update = current_time


def set_avatar_color(color_dict):
    for part, config in color_dict.items():
        indices = AVATAR_LED_MAP[part]
        color = config.get("color")
        is_pulsing = config.get("pulsing", False)

        if is_pulsing:
            active_pulsing_parts[part] = color
        else:
            active_pulsing_parts.pop(part, None)
            for i in indices:
                np[i] = color
    np.write()


def send_serial(component_type, pin_num, name, func, state):
    data = {"type": component_type, "pin": pin_num, "name": name, "function": func, "button_states": state, "avatar": current_avatar_state}
    print(json.dumps(data))


# ==========================================
# INITIALIZATION
# ==========================================
pins = {}
button_states_new = {}
last_debounce_time = {}
color_to_fade = None
slider_percent = 0
current_displayed_image = ""

for pin_num, config in list(BUTTONS.items()) + list(TOGGLES.items()):
    pin = Pin(pin_num, Pin.IN, Pin.PULL_UP)
    pins[pin_num] = pin
    name = config["name"]
    button_states_new[name] = pin.value()
    last_debounce_time[pin_num] = 0

for name, value in button_states_new.items():
    if value == 1:
        state = "ON"
    else :
        state = "OFF"
    print(f"{name} has state {state}")

np = neopixel.NeoPixel(Pin(NEO_PIN), NUM_LEDS)
adc = ADC(ADC_PIN)

set_color({i: COLOR_OFF for i in range(NUM_LEDS)})
display1.fill(RED)
print(json.dumps({"info": "Pico Macro Pad & Displays Started"}))

# Main Loop Variables
voltage_samples = []
last_adc_read_time = 0
last_avatar_eval_time = 0
current_avatar_state = "none"  # Forces the avatar code to set the base color immediately

ADC_SAMPLE_INTERVAL = 4
AVATAR_EVAL_INTERVAL = 400

# ==========================================
# MAIN LOOP
# ==========================================
while True:
    current_time = time.ticks_ms()

    # 1. CHECK PUSH BUTTONS
    for pin_num in BUTTONS.keys():
        name = BUTTONS[pin_num]["name"]
        current_value = pins[pin_num].value()
        if current_value != button_states_new[name]:
            if time.ticks_diff(current_time, last_debounce_time[pin_num]) > DEBOUNCE_DELAY:
                if current_value == 0:
                    if current_avatar_state != "none":
                        send_serial("button", pin_num, name, BUTTONS[pin_num]["func"], "pressed")

                    # --- START FADE TRIGGER ---
                    print(f"{name} should assign color")
                    is_fading = True
                    fade_start_time = current_time
                    if name == "Button 1":
                        color = COLOR_OFF
                    elif name == "Button2":
                        color = RGB_WHITE
                    elif name == "Button 3":
                        color = RGB_BLUE
                    elif name == "Button 4":
                        color = RGB_RED
                    elif name == "Button 5":
                        color = RGB_RED
                    else:
                        color = RGB_WHITE
                    color_to_fade = color
                    for i in AVATAR_LED_MAP["head"]:
                        np[i] = color
                    np.write()
                    # --------------------------

                button_states_new[name] = current_value
                last_debounce_time[pin_num] = current_time

    # 2. CHECK TOGGLES
    for pin_num in TOGGLES.keys():
        name = TOGGLES[pin_num]["name"]
        current_value = pins[pin_num].value()
        if current_value != button_states_new[name]:
            if time.ticks_diff(current_time, last_debounce_time[pin_num]) > DEBOUNCE_DELAY:
                state_str = "ON" if current_value == 0 else "OFF"
                if current_avatar_state != "none":
                    send_serial("toggle", pin_num, name, TOGGLES[pin_num]["func"], state_str)
                button_states_new[name] = current_value
                last_debounce_time[pin_num] = current_time

    # Update Mouth Color based on Toggle 4 (Only triggers when necessary)
    mouth_target = RGB_RED if button_states_new.get("Toggle 4", 0) == 1 else COLOR_OFF
    if np[AVATAR_LED_MAP["mouth"][0]] != mouth_target:
        set_avatar_color({"mouth": {"color": mouth_target, "pulsing": False}})

    # 3. NON-BLOCKING ADC SAMPLING
    if time.ticks_diff(current_time, last_adc_read_time) >= ADC_SAMPLE_INTERVAL:
        voltage_samples.append(adc.read_u16())
        if len(voltage_samples) > 8:
            voltage_samples.pop(0)
        last_adc_read_time = current_time

    # 4. AVATAR & DISPLAY LOGIC
    if time.ticks_diff(current_time, last_avatar_eval_time) >= AVATAR_EVAL_INTERVAL:
        if len(voltage_samples) == 8:
            avg_raw = sum(voltage_samples) / 8
            v = (avg_raw / 65535) * 3.3

            new_state = "none"
            new_color = {i: COLOR_OFF for i in range(NUM_LEDS)}

            if v <= NO_AVATAR_MAX:
                new_state = "none"
                print("no av")
                new_colour = {
                    "head": {"color": COLOR_OFF, "pulsing": False},
                    "eyes": {"color": COLOR_OFF, "pulsing": False},
                    "mouth": {"color": COLOR_OFF, "pulsing": False}
                }
            elif AV1_47K_MIN <= v <= AV1_47K_MAX:
                new_state = "av1"
                print("av1")
                new_colour = {
                    "head": {"color": COLOR_AV1, "pulsing": False},
                    "eyes": {"color": COLOR_OFF, "pulsing": True},
                    "mouth": {"color": COLOR_OFF, "pulsing": False}
                }
            elif AV2_20K_MIN <= v <= AV2_20K_MAX:
                new_state = "av2"
                print("av2")
                new_colour = {
                    "head": {"color": COLOR_AV2, "pulsing": False},
                    "eyes": {"color": COLOR_OFF, "pulsing": True},
                    "mouth": {"color": COLOR_OFF, "pulsing": False}
                }
            else:
                new_state = "none"
                print("no av")
                new_colour = {
                    "head": {"color": COLOR_OFF, "pulsing": False},
                    "eyes": {"color": COLOR_OFF, "pulsing": False},
                    "mouth": {"color": COLOR_OFF, "pulsing": False}
                }

            # EXECUTE CHANGE
            if new_state != current_avatar_state:
                set_avatar_color(new_colour)

                # Update our fade target so it always knows what color to return to
                current_base_head_color = new_colour["head"]["color"]
                current_avatar_state = new_state

        last_avatar_eval_time = current_time

    slider_value = slider.read_u16()
    if abs(slider_value - last_slider_value) > 2000:
        slider_percent = (slider_value / 65535) * 100
        print(f"[SLIDER] Value: {slider_value} ({slider_percent:.1f}%)")
        last_slider_value = slider_value
    target_image = current_displayed_image  # Default to no change
    if current_avatar_state == "none":
        target_image = "no_avatar.bmp"
    else:
        if slider_percent < 25:
            target_image = "avatar1_on.bmp" if current_avatar_state == "av1" else "avatar2_on.bmp"
        elif 25 <= slider_percent <= 50:
            target_image = "avatar1_blur1.bmp" if current_avatar_state == "av1" else "avatar2_blur1.bmp"
        elif slider_percent <= 75:
            target_image = "avatar1_blur2.bmp" if current_avatar_state == "av1" else "avatar2_blur2.bmp"
        elif slider_percent > 75:
            target_image = "avatar1_off.bmp" if current_avatar_state == "av1" else "avatar2_off.bmp"

    # Only draw to the screen if the target image is different from the currently displayed image
    if target_image != current_displayed_image:
        if target_image != "":  # Prevent blank loads on initial startup
            draw_bmp_to_display1(target_image)
        current_displayed_image = target_image

    # Evaluate target color based on slider percentage
    if slider_percent < 75:
        eyes_target = RGB_RED
    elif slider_percent > 75:
        eyes_target = COLOR_OFF
    else:
        eyes_target = None  # No change to LED state between 25% and 75%

    # Apply color if a target is defined and the current state doesn't match
    if eyes_target is not None and np[AVATAR_LED_MAP["eyes"][0]] != eyes_target:
        set_avatar_color({"eyes": {"color": eyes_target, "pulsing": False}})


    # 5. EXECUTE FADE LOGIC
    if is_fading:
        elapsed = time.ticks_diff(current_time, fade_start_time)
        if elapsed < fade_duration:
            current_fade_color = interpolate_color(color_to_fade, current_base_head_color, elapsed, fade_duration)
            for i in AVATAR_LED_MAP["head"]:
                np[i] = current_fade_color
            np.write()
        else:
            is_fading = False
            for i in AVATAR_LED_MAP["head"]:
                np[i] = current_base_head_color
            np.write()

    # 6. EXECUTE PULSING (For the eyes)
    update_pulsing()

    # 7. UPDATE AUDIO METER (Display 2)
    update_audio_meter(current_avatar_state)

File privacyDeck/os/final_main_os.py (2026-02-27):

import tkinter as tk
import threading
import time
import os
import json

import serial
from serial.tools import list_ports

from mic_control import set_mic_mute
from lock_control import lock_os
from clipboard_control import wipe_clipboard_history
from usb_alert_control import toggle_usb_alert
from airplane import gui_toggle_airplane_mode
from location import gui_toggle_location
from blackout import show_blackout_image
from webcam import WebcamController
from audio_meter import AudioMeterWidget


# ===== STATE =====

mic_is_muted = False
usb_alert_is_on = False
airplane_mode_is_on = False
location_is_on = False

SERIAL_PORT = os.getenv("PICO_SERIAL_PORT")
SERIAL_BAUDRATE = 115200
# test
FUNCTION_TO_ACTION = {
    "Lock OS": "lock_system",
    "wipe clipboard history": "wipe_clipboard",
    "mic mute toggle": "toggle_mic",
    "airplane mode": "toggle_airplane",
    "blackout/presentation mode": "show_blackout",
    "usb alert": "toggle_usb",
    "browser clean": "toggle_airplane",
    "gps mode": None,
    "Instant Privacy": "instant_privacy",
}


class PicoSerialListener:
    def __init__(self, port, baudrate, event_callback, status_callback):
        self.port = port
        self.baudrate = baudrate
        self.event_callback = event_callback
        self.status_callback = status_callback
        self._stop_event = threading.Event()
        self._serial = None
        self._thread = None

    def start(self):
        if self._thread is not None:
            return
        self._thread = threading.Thread(target=self._run_listener, daemon=True)
        self._thread.start()

    def stop(self):
        self._stop_event.set()
        if self._serial is not None:
            try:
                self._serial.close()
            except Exception:
                pass

    def _resolve_port(self):
        if self.port:
            return self.port

        for item in list_ports.comports():
            device = (item.device or "").lower()
            description = (item.description or "").lower()
            if "ttyacm" in device or "ttyusb" in device:
                return item.device
            if "pico" in description or "rp2040" in description:
                return item.device
        return None

    def _run_listener(self):
        self.status_callback("Serial: waiting for Pico...")
        while not self._stop_event.is_set():
            port = self._resolve_port()
            if not port:
                self.status_callback("Serial: no device found")
                time.sleep(2.0)
                continue

            try:
                ser = serial.Serial(port=port, baudrate=self.baudrate, timeout=1.0)
                self._serial = ser
                try:
                    ser.reset_input_buffer()
                except Exception:
                    pass
                self.status_callback(f"Serial: connected on {port}")

                while not self._stop_event.is_set():
                    raw = ser.readline()
                    if not raw:
                        continue
                    line = raw.decode("utf-8", errors="replace").strip()
                    if not line:
                        continue
                    
                    try:
                        data = json.loads(line)
                    except json.JSONDecodeError:
                        continue
                        
                    if "function" not in data:
                        continue
                        
                    print(f"[SERIAL RX] {line}")
                    self._dispatch_event(data)
            except (serial.SerialException, OSError):
                self.status_callback("Serial: disconnected, retrying...")
                time.sleep(1.5)
            finally:
                if self._serial is not None:
                    try:
                        self._serial.close()
                    except Exception:
                        pass
                self._serial = None

        self.status_callback("Serial: stopped")

    def _dispatch_event(self, data):
        func = data.get("function")
        if func not in FUNCTION_TO_ACTION:
            print(f"[IGNORED] unknown function: {func}")
            return

        action = FUNCTION_TO_ACTION[func]
        if action is None:
            print(f"[IGNORED] no daemon action for: {func}")
            return

        print(f"[CALL] {action}")
        self.event_callback(action, data)


# ===== CALLBACKS =====

def toggle_mic():
    global mic_is_muted
    mic_is_muted = not mic_is_muted
    set_mic_mute(mic_is_muted)
    btn_toggle_mic.config(
        text=f"Toggle: Mic {'Muted' if mic_is_muted else 'Active'}"
    )

def set_mic_state(mute):
    global mic_is_muted
    mic_is_muted = mute
    set_mic_mute(mic_is_muted)
    btn_toggle_mic.config(
        text=f"Toggle: Mic {'Muted' if mic_is_muted else 'Active'}"
    )


def lock_system():
    lock_os()


def wipe_clipboard():
    wipe_clipboard_history()


def show_blackout(img_name="img1.jpg"):
    import blackout
    old_join = blackout.os.path.join
    def new_join(*args):
        if args and args[-1] == "img1.jpg":
            return old_join(*args[:-1], img_name)
        return old_join(*args)
    blackout.os.path.join = new_join
    try:
        show_blackout_image()
    finally:
        blackout.os.path.join = old_join


def toggle_usb():
    global usb_alert_is_on
    usb_alert_is_on = not usb_alert_is_on
    toggle_usb_alert(usb_alert_is_on)
    btn_toggle_usb.config(
        text=f"Toggle: USB Alert {'ON' if usb_alert_is_on else 'OFF'}"
    )


def toggle_airplane_mode():
    global airplane_mode_is_on
    success = gui_toggle_airplane_mode()
    if success:
        airplane_mode_is_on = not airplane_mode_is_on

    btn_toggle_airplane.config(
        text=f"Toggle: Airplane Mode {'ON' if airplane_mode_is_on else 'OFF'}"
    )


def toggle_location():
    global location_is_on
    success = gui_toggle_location()
    if success:
        location_is_on = not location_is_on

    btn_toggle_location.config(
        text=f"Toggle: Location {'ON' if location_is_on else 'OFF'}"
    )


def set_webcam_privacy(value):
    webcam_controller.set_privacy_level(value)


def update_network_status(text):
    root.after(0, lambda: network_status_label.config(text=text))
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

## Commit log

2026-02-21 using external webcam on linux, as my internal is broken
    [webcam.py]
2026-02-25 Display Driver Implementations
2026-02-25 good freeze, all buttons and toggles working
2026-02-27 final pico
2026-03-04 add first 3d models to codebase
    [Fonts.stl, Icons.stl, component_list.xlsx]
2026-03-04 added stls and bmps
    [AvatarBase.stl, AvatarHead.stl, AvatarInsert.stl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]
2026-03-04 stl in lasercut
    [PrivacyDeckTop.stl]
